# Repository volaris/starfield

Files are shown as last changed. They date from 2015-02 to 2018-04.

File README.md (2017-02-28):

Starfield
=========

Software (simulation and control) and electronics for the starfield display.

## Overview

The Starfield is a large grid of color controllable LEDs. They're spaced on vertical strands so that people can walk through them. People will be able to watch it from afar, walk through, or lounge in the space. There will be ambient animations designed to calm and intrigue. Calming music will play throughout the space. At certain times a DJ can connect to the Starfield or it picks up noise in the environment and displays animations that enhance and respond to that sound. IR cameras will detect where people are in the space and how active they are and modify the animations to respond to them. In the future, hand tracking stations will be used to create an individual or collaborative animation looper. Other methods of interaction such as converting EEG patterns to light are being investigated. The first version is a prototype designed to fit in a living room. A 20'x20'x20' version is being constructed for [Critical NW 2015](http://www.criticalnw.org/) and an even larger one is being planned for Burning Man 2016.

## Get Involved

Read the developer's guide and documentation at [volaris.github.io/starfield](http://volaris.github.io/starfield/)

## Technical Details

The core of the Starfield is driven by a [Fadecandy](https://github.com/scanlime/fadecandy) running on a [Raspberry Pi](https://www.raspberrypi.org/).

### Prototype

The prototype Starfield is a 7x5x4 voxel grid designed for hardware, animation, and construction technique testing.

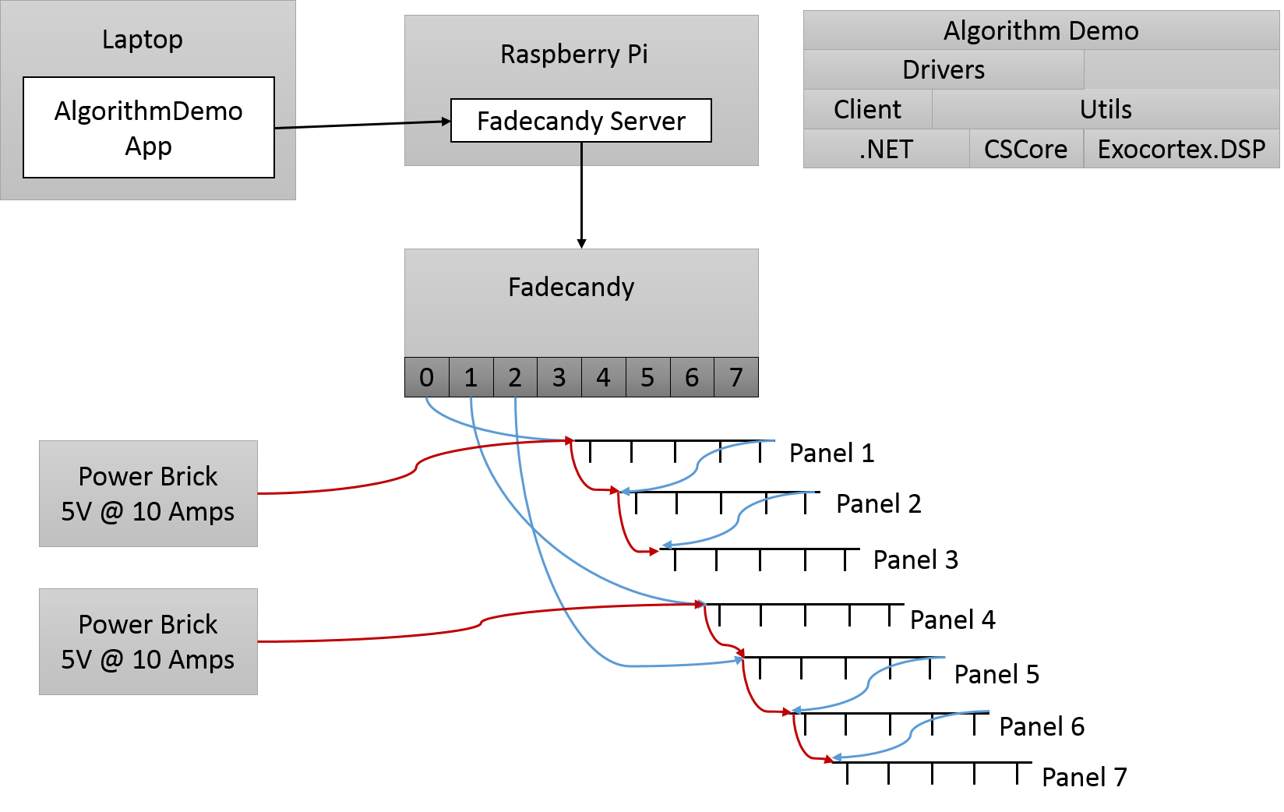
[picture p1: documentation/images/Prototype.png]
Prototype Diagram


### Critical NW

The Critical NW Starfield is a 11x11x10 voxel grid.

### Burning Man

The Burning Man Starfield is a 16x16x15 voxel grid.

## Repository Layout
```
/starfield
    /controllers - Starfield drivers and control software
        /AlgorithmDemo - Single display algorithm wrapper, displays list of all available drivers and their configuration options
        /Ambient - Randomly cycles through ambient algorithms
        /DualController - like AlgorithmDemo except it splits the display and displays two different algorithms
        /StarfieldDrivers - all of the driver classes, the controllers listed above use reflection to enumerate the drivers and their types from this library
    /docs - Starfield documentation for generating [volaris.github.io/starfield](http://volaris.github.io/starfield/)
    /documentation - Papers, datasheets, images related to algorithms 
    /electronics - Electronics designs: power distribution, voxel design, etc.
    /lib - Shared code and utility classes
        /.NET - .NET utility classes
            /StarfieldClient - base starfield classes, types, and interfaces (includes display model, driver interface, and network protocols)
            /Utils - Math, color, sound, and other algorithm utilities
        /external - 3rd party libraries
    /mechanical - Mechanical engineering designs and calculations for the structure
    /simulator - Unity simulator
```

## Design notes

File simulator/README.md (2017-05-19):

Starfield
=========

Unity based simulator for the starfield.

## Usage

After running the executable, use the configuration panel to generate the Starfield size that you want to interract with.
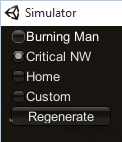
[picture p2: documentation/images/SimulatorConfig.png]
Simulator Config


## Connecting

The simulator opens a localhost TCP socket on port 7890 (127.0.0.1:7890). This socket accepts OPC pixel data.

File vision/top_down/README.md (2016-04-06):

Starfield Vision System
=======================

Software to capture and process IR images. This version assumes that cameras are facing straight down from the center support structure.

## image_aggregator.py
Retrieves the images from the remote cameras and prepares them for image_blender.py.

## image_blender.py
Takes the 5 images and blends them into a single image for heat map processing.

## image_processor.py
Takes the output from image_blender.py and creates a json file indicating the current presence levels for each grid coordinate.

## activity_processor.py
Takes the current output from image_blender.py and combines it with historical data to get a change in presence measure. Outputs a json file.

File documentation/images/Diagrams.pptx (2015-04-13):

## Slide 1

AlgorithmDemo App

Laptop

Raspberry Pi

Fadecandy Server

Algorithm Demo

Drivers

Utils

.NET

Client

CSCore

Exocortex.DSP

Fadecandy

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
Panel 1

Power Brick
5V @ 10 Amps

Power Brick
5V @ 10 Amps

Panel 2

Panel 3

Panel 4

Panel 5

Panel 6

Panel 7

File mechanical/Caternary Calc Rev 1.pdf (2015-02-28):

w 5

lbf
ft

:= Load per unit length

Half distance to support (a=x) | a | 50ft :=
Allowable Sag | S := 5ft
Guess for equation | c := 32ft

Given

S | c cosh a
| c

− 1

= ⋅

c
1

:= Find c( )

Caternary parameter | c
1

= 250.829 ft

s c
1

sinh a
c
1

:= ⋅

Length of cable to half (L=s) | s | 50.332 ft =

y
d

c
1
:= | + S
Height of post | y
d

= 255.829 ft

Tension at point of lowest sag | H | w c1
:= ⋅ | H | 1254.145 lbf =

Distributed Load
F := w s⋅ | F | 251.659 lbf =
Tension at support | T | w yd
:= ⋅ | T | 1279.145 lbf =

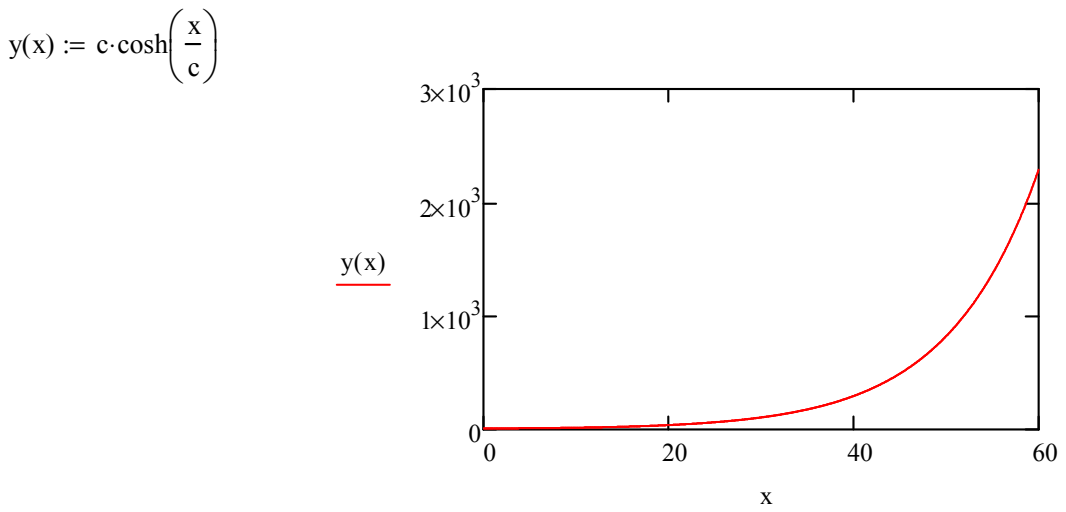
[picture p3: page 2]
c cosh

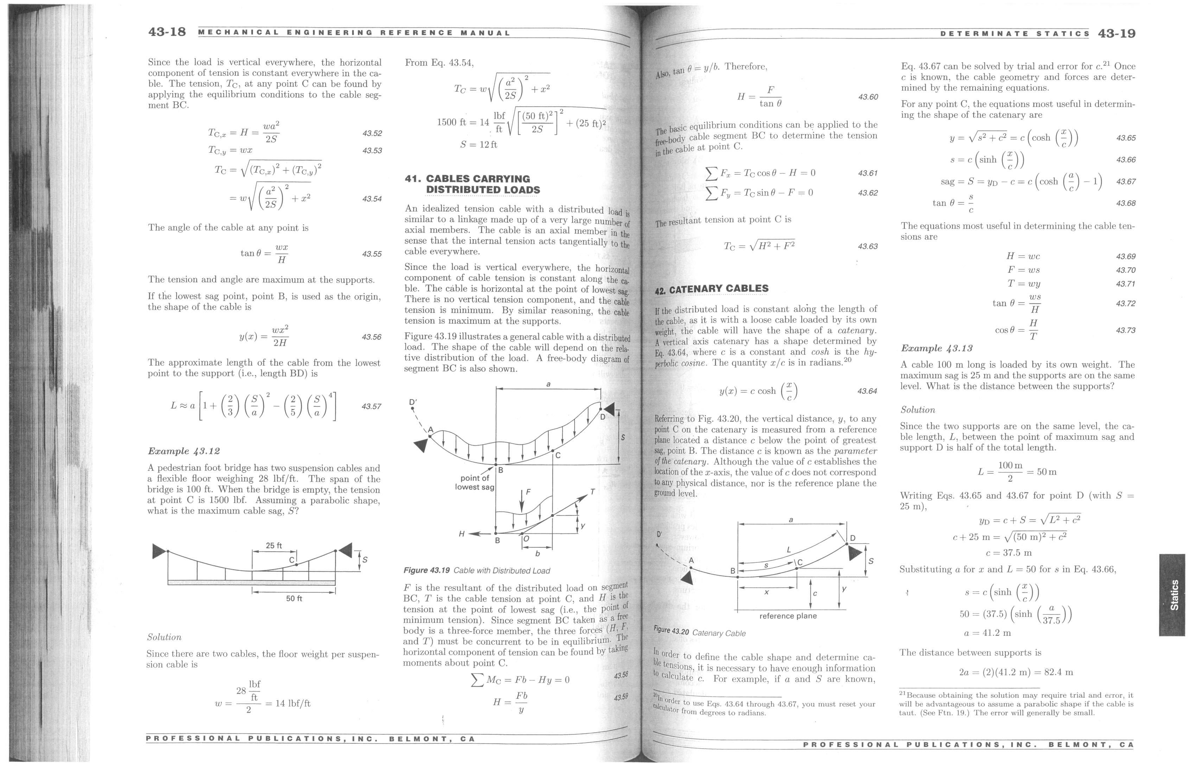
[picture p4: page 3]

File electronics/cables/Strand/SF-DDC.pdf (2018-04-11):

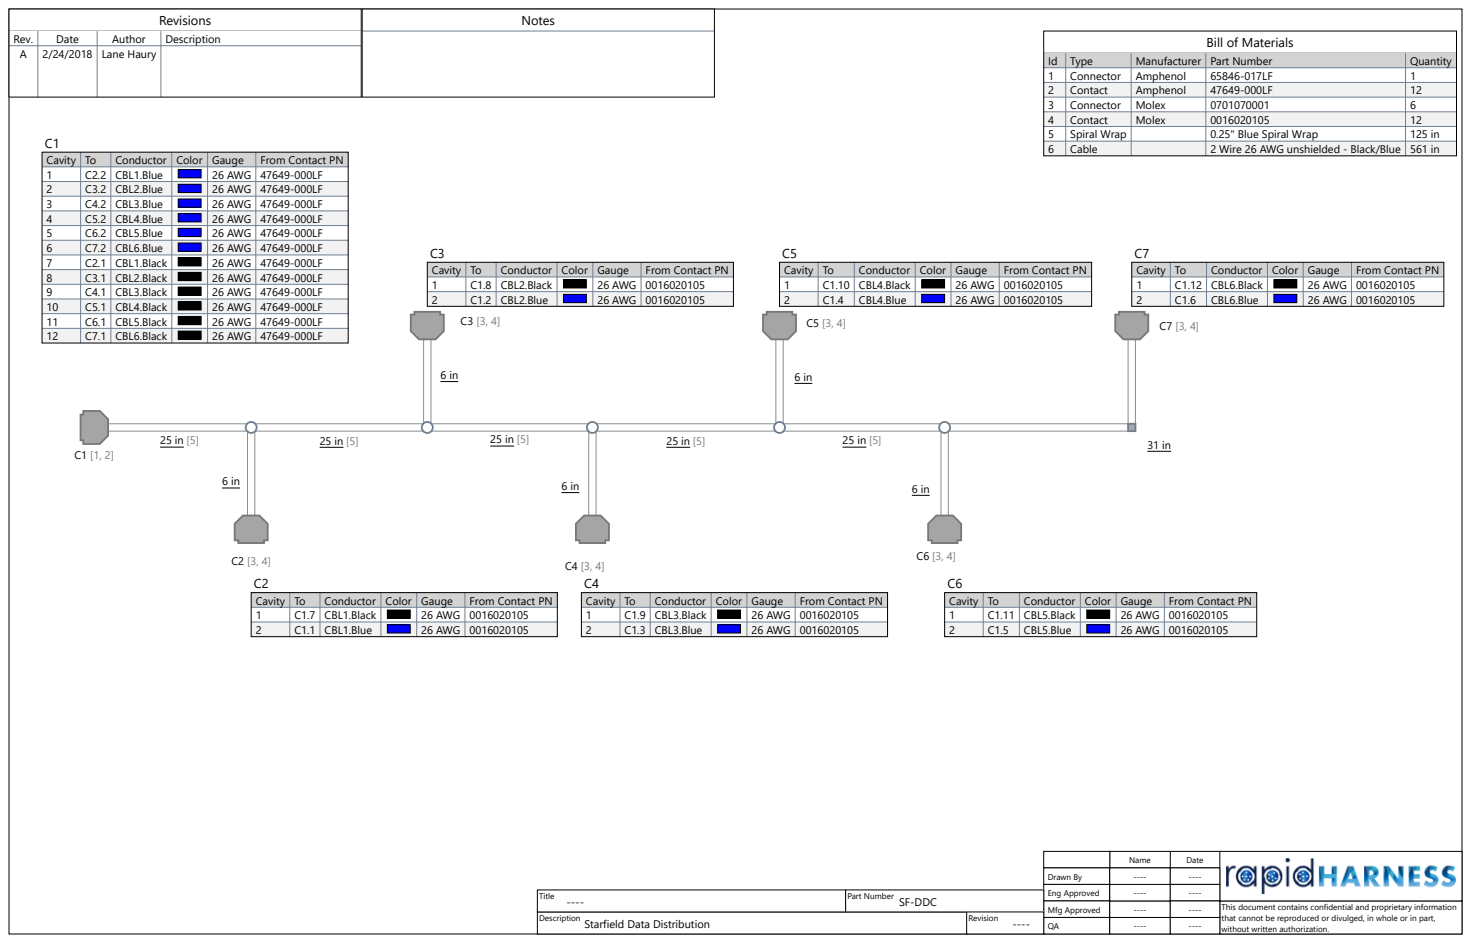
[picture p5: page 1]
Description; Name; Date; Drawn By; Eng Approved; Mfg Approved; Part Number; Revision; Title; SF-DDC; Starfield Data Distribution; Type; Manufacturer; Quantity; Connector; Amphenol; Contact; Molex; Spiral Wrap; 0.25" Blue Spiral Wrap; Cable; 2 Wire 26 AWG unshielded - Black/Blue; Revisions; Notes; Rev.; Author; Lane Haury; Cavity; Conductor; Color; Gauge; From Contact PN; CBL6.Black; 26 AWG; CBL6.Blue; CBL5.Black; CBL5.Blue; CBL4.Black; CBL4.Blue; CBL3.Black; CBL3.Blue; CBL2.Black; CBL2.Blue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

Bill of Materials

This document contains confidential and proprietary information
that cannot be reproduced or divulged, in whole or in part,
without written authorization.

Id | Type | Manufacturer | Part Number | Description | Quantity
1 | Connector | Amphenol | 65846-017LF | 2x6 Socket Connector | 1
2 | Contact | Amphenol | 47649-000LF | 22-26AWG Crimp Socket | 12
3 | Connector | Molex | 0701070001 | 2 pin locking | 6
4 | Contact | Molex | 0016020105 | 24-30AWG Pin | 12
5 | Spiral Wrap | | 0.25" Blue Spiral Wrap | Generic Spiral Wrap - Nylon | 125 in
6 | Cable | | 2 Wire 26 AWG unshielded - Black/Blue | Generic Cable | 561 in
Bill of Materials 1 of 1 | Page 2 of 5

Title:

Part Number: | SF-DDC
Description: | Starfield Data Distribution

From | To | Conductor | Conductor PN | Twist With | Gauge | Length | From Contact PN | Notes
C1.1 | C2.2 | CBL1.Blue | 2 Wire 26 AWG unshielded - Black/Blue | | 26 AWG | 31 in | 47649-000LF
C1.2 | C3.2 | CBL2.Blue | 2 Wire 26 AWG unshielded - Black/Blue | | 26 AWG | 56 in | 47649-000LF
C1.3 | C4.2 | CBL3.Blue | 2 Wire 26 AWG unshielded - Black/Blue | | 26 AWG | 81 in | 47649-000LF
C1.4 | C5.2 | CBL4.Blue | 2 Wire 26 AWG unshielded - Black/Blue | | 26 AWG | 106 in | 47649-000LF
C1.5 | C6.2 | CBL5.Blue | 2 Wire 26 AWG unshielded - Black/Blue | | 26 AWG | 131 in | 47649-000LF
C1.6 | C7.2 | CBL6.Blue | 2 Wire 26 AWG unshielded - Black/Blue | | 26 AWG | 156 in | 47649-000LF
C1.7 | C2.1 | CBL1.Black | 2 Wire 26 AWG unshielded - Black/Blue | | 26 AWG | 31 in | 47649-000LF
C1.8 | C3.1 | CBL2.Black | 2 Wire 26 AWG unshielded - Black/Blue | | 26 AWG | 56 in | 47649-000LF
C1.9 | C4.1 | CBL3.Black | 2 Wire 26 AWG unshielded - Black/Blue | | 26 AWG | 81 in | 47649-000LF
C1.10 | C5.1 | CBL4.Black | 2 Wire 26 AWG unshielded - Black/Blue | | 26 AWG | 106 in | 47649-000LF
C1.11 | C6.1 | CBL5.Black | 2 Wire 26 AWG unshielded - Black/Blue | | 26 AWG | 131 in | 47649-000LF
C1.12 | C7.1 | CBL6.Black | 2 Wire 26 AWG unshielded - Black/Blue | | 26 AWG | 156 in | 47649-000LF
Wiring Table 1 of 1 | Page 3 of 5

Description:

Starfield Data Distribution

# | Type | Reference Designator | Manufacturer | Part Number | Color | Gauge | Length | Twisted With

1 | Cable | CBL1 | 2 Wire 26 AWG unshielded - Black/Blue | White | 31 in
2 | Cable | CBL2 | 2 Wire 26 AWG unshielded - Black/Blue | White | 56 in
3 | Cable | CBL3 | 2 Wire 26 AWG unshielded - Black/Blue | White | 81 in
4 | Cable | CBL4 | 2 Wire 26 AWG unshielded - Black/Blue | White | 106 in
5 | Cable | CBL5 | 2 Wire 26 AWG unshielded - Black/Blue | White | 131 in
6 | Cable | CBL6 | 2 Wire 26 AWG unshielded - Black/Blue | White | 156 in
Cutlist 1 of 1 | Page 4 of 5

Description:

Starfield Data Distribution

# | Manufacturer | Part Number | Description | Label Text

Labels 1 of 1 | Page 5 of 5

Description:

Starfield Data Distribution

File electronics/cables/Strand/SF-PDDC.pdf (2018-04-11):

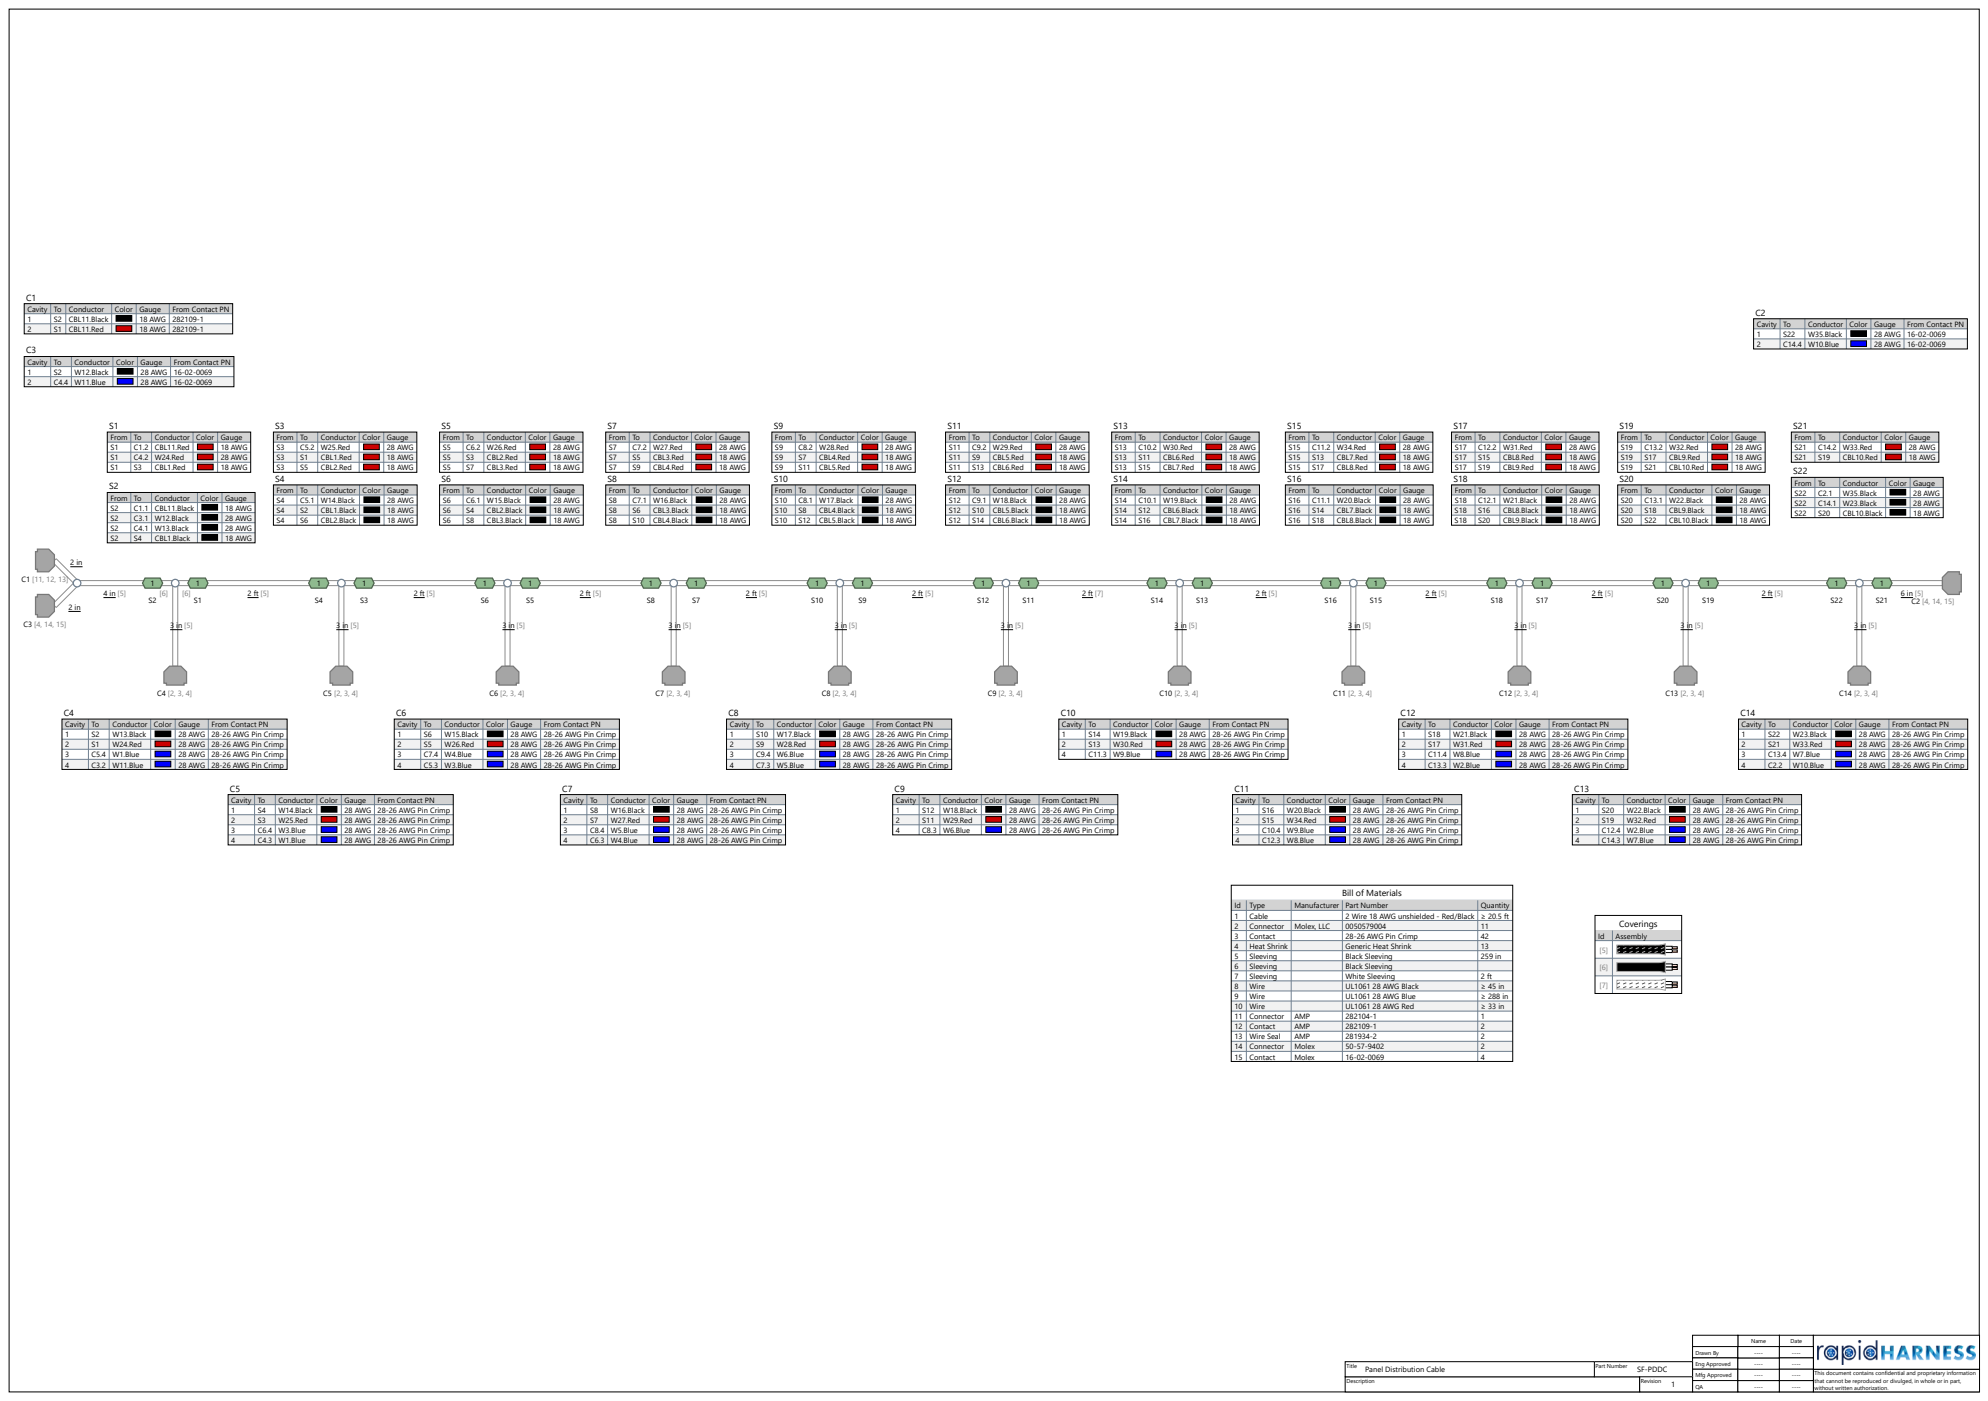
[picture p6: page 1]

This document contains confidential and proprietary information
that cannot be reproduced or divulged, in whole or in part,
without written authorization.

Id | Type | Manufacturer | Part Number | Description | Quantity
1 | Cable | | 2 Wire 18 AWG unshielded - Red/Black | Generic Cable | ≥ 20.5 ft
2 | Connector | Molex, LLC | 0050579004 | CONN HOUSING 4POS .100 SINGLE | 11
3 | Contact | | 28-26 AWG Pin Crimp | Generic Contact | 42
4 | Heat Shrink | | Generic Heat Shrink | Generic Heat Shrink | 13
5 | Sleeving | | Black Sleeving | Generic Sleeving - Kevlar, Braided | 259 in
6 | Sleeving | | Black Sleeving | Generic Sleeving - Kevlar
7 | Sleeving | | White Sleeving | Generic Sleeving - Kevlar, Braided | 2 ft
8 | Wire | | UL1061 28 AWG Black | UL 1061 rated 28 AWG Black SR-PVC Hook-up wire | ≥ 45 in
9 | Wire | | UL1061 28 AWG Blue | UL 1061 rated 28 AWG Blue SR-PVC Hook-up wire | ≥ 288 in
10 | Wire | | UL1061 28 AWG Red | UL 1061 rated 28 AWG Red SR-PVC Hook-up wire | ≥ 33 in
11 | Connector | AMP | 282104-1 | AMP SUPERSEAL 1.5 SERIES 2P CA | 1
12 | Contact | AMP | 282109-1 | AMP MINI MIC TAB CONTACT | 2
13 | Wire Seal | AMP | 281934-2 | Amp SuperSeal 1.5 Single Wire Seal | 2
14 | Connector | Molex | 50-57-9402 | 2 Position Rectangular Housing Connector Receptacle Black 0.100" (2.54mm) 2
15 | Contact | Molex | 16-02-0069 | Socket Contact Tin 24-30 AWG Crimp
Bill of Materials 1 of 1 | Page 2 of 6

# Part Number:

# Title:

# Description:

From | To | Conductor | Conductor PN | Twist With | Gauge | Length | From Contact PN | Notes
C1.1 | S2 | CBL11.Black | 2 Wire 18 AWG unshielded - Red/Black | | 18 AWG | ≥ 6 in | 282109-1
C1.2 | S1 | CBL11.Red | 2 Wire 18 AWG unshielded - Red/Black | | 18 AWG | ≥ 6 in | 282109-1
C2.1 | S22 | W35.Black | UL1061 28 AWG Black | | 28 AWG | ≥ 6 in | 16-02-0069
C2.2 | C14.4 | W10.Blue | UL1061 28 AWG Blue | | 28 AWG | ≥ 9 in | 16-02-0069
C3.1 | S2 | W12.Black | UL1061 28 AWG Black | | 28 AWG | 6 in | 16-02-0069
C3.2 | C4.4 | W11.Blue | UL1061 28 AWG Blue | | 28 AWG | ≥ 9 in | 16-02-0069
C4.1 | S2 | W13.Black | UL1061 28 AWG Black | | 28 AWG | ≥ 3 in | 28-26 AWG Pin Crimp
C4.2 | S1 | W24.Red | UL1061 28 AWG Red | | 28 AWG | ≥ 3 in | 28-26 AWG Pin Crimp
C4.3 | C5.4 | W1.Blue | UL1061 28 AWG Blue | | 28 AWG | ≥ 30 in | 28-26 AWG Pin Crimp
C5.1 | S4 | W14.Black | UL1061 28 AWG Black | | 28 AWG | ≥ 3 in | 28-26 AWG Pin Crimp
C5.2 | S3 | W25.Red | UL1061 28 AWG Red | | 28 AWG | ≥ 3 in | 28-26 AWG Pin Crimp
C5.3 | C6.4 | W3.Blue | UL1061 28 AWG Blue | | 28 AWG | ≥ 30 in | 28-26 AWG Pin Crimp
C6.1 | S6 | W15.Black | UL1061 28 AWG Black | | 28 AWG | ≥ 3 in | 28-26 AWG Pin Crimp
C6.2 | S5 | W26.Red | UL1061 28 AWG Red | | 28 AWG | ≥ 3 in | 28-26 AWG Pin Crimp
C6.3 | C7.4 | W4.Blue | UL1061 28 AWG Blue | | 28 AWG | ≥ 30 in | 28-26 AWG Pin Crimp
C7.1 | S8 | W16.Black | UL1061 28 AWG Black | | 28 AWG | ≥ 3 in | 28-26 AWG Pin Crimp
C7.2 | S7 | W27.Red | UL1061 28 AWG Red | | 28 AWG | ≥ 3 in | 28-26 AWG Pin Crimp
C7.3 | C8.4 | W5.Blue | UL1061 28 AWG Blue | | 28 AWG | ≥ 30 in | 28-26 AWG Pin Crimp
C8.1 | S10 | W17.Black | UL1061 28 AWG Black | | 28 AWG | ≥ 3 in | 28-26 AWG Pin Crimp
C8.2 | S9 | W28.Red | UL1061 28 AWG Red | | 28 AWG | ≥ 3 in | 28-26 AWG Pin Crimp
C8.3 | C9.4 | W6.Blue | UL1061 28 AWG Blue | | 28 AWG | ≥ 30 in | 28-26 AWG Pin Crimp
C9.1 | S12 | W18.Black | UL1061 28 AWG Black | | 28 AWG | ≥ 3 in | 28-26 AWG Pin Crimp
C9.2 | S11 | W29.Red | UL1061 28 AWG Red | | 28 AWG | ≥ 3 in | 28-26 AWG Pin Crimp
C10.1 | S14 | W19.Black | UL1061 28 AWG Black | | 28 AWG | ≥ 3 in | 28-26 AWG Pin Crimp
C10.2 | S13 | W30.Red | UL1061 28 AWG Red | | 28 AWG | ≥ 3 in | 28-26 AWG Pin Crimp
C11.1 | S16 | W20.Black | UL1061 28 AWG Black | | 28 AWG | ≥ 3 in | 28-26 AWG Pin Crimp
C11.2 | S15 | W34.Red | UL1061 28 AWG Red | | 28 AWG | ≥ 3 in | 28-26 AWG Pin Crimp
C11.3 | C10.4 | W9.Blue | UL1061 28 AWG Blue | | 28 AWG | ≥ 30 in | 28-26 AWG Pin Crimp
C12.1 | S18 | W21.Black | UL1061 28 AWG Black | | 28 AWG | ≥ 3 in | 28-26 AWG Pin Crimp
C12.2 | S17 | W31.Red | UL1061 28 AWG Red | | 28 AWG | ≥ 3 in | 28-26 AWG Pin Crimp
C12.3 | C11.4 | W8.Blue | UL1061 28 AWG Blue | | 28 AWG | ≥ 30 in | 28-26 AWG Pin Crimp
C13.1 | S20 | W22.Black | UL1061 28 AWG Black | | 28 AWG | ≥ 3 in | 28-26 AWG Pin Crimp
C13.2 | S19 | W32.Red | UL1061 28 AWG Red | | 28 AWG | ≥ 3 in | 28-26 AWG Pin Crimp
C13.3 | C12.4 | W2.Blue | UL1061 28 AWG Blue | | 28 AWG | ≥ 30 in | 28-26 AWG Pin Crimp
C14.1 | S22 | W23.Black | UL1061 28 AWG Black | | 28 AWG | ≥ 3 in | 28-26 AWG Pin Crimp
C14.2 | S21 | W33.Red | UL1061 28 AWG Red | | 28 AWG | ≥ 3 in | 28-26 AWG Pin Crimp
C14.3 | C13.4 | W7.Blue | UL1061 28 AWG Blue | | 28 AWG | ≥ 30 in | 28-26 AWG Pin Crimp
S1 | S3 | CBL1.Red | 2 Wire 18 AWG unshielded - Red/Black | | 18 AWG | ≥ 2 ft
S2 | S4 | CBL1.Black | 2 Wire 18 AWG unshielded - Red/Black | | 18 AWG | ≥ 2 ft
S3 | S5 | CBL2.Red | 2 Wire 18 AWG unshielded - Red/Black | | 18 AWG | ≥ 2 ft
S4 | S6 | CBL2.Black | 2 Wire 18 AWG unshielded - Red/Black | | 18 AWG | ≥ 2 ft
S5 | S7 | CBL3.Red | 2 Wire 18 AWG unshielded - Red/Black | | 18 AWG | ≥ 2 ft
S6 | S8 | CBL3.Black | 2 Wire 18 AWG unshielded - Red/Black | | 18 AWG | ≥ 2 ft
S7 | S9 | CBL4.Red | 2 Wire 18 AWG unshielded - Red/Black | | 18 AWG | ≥ 2 ft
S8 | S10 | CBL4.Black | 2 Wire 18 AWG unshielded - Red/Black | | 18 AWG | ≥ 2 ft
S9 | S11 | CBL5.Red | 2 Wire 18 AWG unshielded - Red/Black | | 18 AWG | ≥ 2 ft
S10 | S12 | CBL5.Black | 2 Wire 18 AWG unshielded - Red/Black | | 18 AWG | ≥ 2 ft
S11 | S13 | CBL6.Red | 2 Wire 18 AWG unshielded - Red/Black | | 18 AWG | ≥ 2 ft
S13 | S15 | CBL7.Red | 2 Wire 18 AWG unshielded - Red/Black | | 18 AWG | ≥ 2 ft
S14 | S12 | CBL6.Black | 2 Wire 18 AWG unshielded - Red/Black | | 18 AWG | ≥ 2 ft
S14 | S16 | CBL7.Black | 2 Wire 18 AWG unshielded - Red/Black | | 18 AWG | ≥ 2 ft
S15 | S17 | CBL8.Red | 2 Wire 18 AWG unshielded - Red/Black | | 18 AWG | ≥ 2 ft
S16 | S18 | CBL8.Black | 2 Wire 18 AWG unshielded - Red/Black | | 18 AWG | ≥ 2 ft
S17 | S19 | CBL9.Red | 2 Wire 18 AWG unshielded - Red/Black | | 18 AWG | ≥ 2 ft
S18 | S20 | CBL9.Black | 2 Wire 18 AWG unshielded - Red/Black | | 18 AWG | ≥ 2 ft
S19 | S21 | CBL10.Red | 2 Wire 18 AWG unshielded - Red/Black | | 18 AWG | ≥ 2 ft
Wiring Table 1 of 2 | Page 3 of 6

From | To | Conductor | Conductor PN | Twist With | Gauge | Length | From Contact PN | Notes
S20 | S22 | CBL10.Black | 2 Wire 18 AWG unshielded - Red/Black | | 18 AWG | ≥ 2 ft
Wiring Table 2 of 2 | Page 4 of 6

# | Type | Reference Designator | Manufacturer | Part Number | Color | Gauge | Length | Twisted With

1 | Cable | CBL1 | 2 Wire 18 AWG unshielded - Red/Black | White | ≥ 2 ft
2 | Cable | CBL2 | 2 Wire 18 AWG unshielded - Red/Black | White | ≥ 2 ft
3 | Cable | CBL3 | 2 Wire 18 AWG unshielded - Red/Black | White | ≥ 2 ft
4 | Cable | CBL4 | 2 Wire 18 AWG unshielded - Red/Black | White | ≥ 2 ft
5 | Cable | CBL5 | 2 Wire 18 AWG unshielded - Red/Black | White | ≥ 2 ft
6 | Cable | CBL6 | 2 Wire 18 AWG unshielded - Red/Black | White | ≥ 2 ft
7 | Cable | CBL7 | 2 Wire 18 AWG unshielded - Red/Black | White | ≥ 2 ft
8 | Cable | CBL8 | 2 Wire 18 AWG unshielded - Red/Black | White | ≥ 2 ft
9 | Cable | CBL9 | 2 Wire 18 AWG unshielded - Red/Black | White | ≥ 2 ft
10 | Cable | CBL10 | 2 Wire 18 AWG unshielded - Red/Black | White | ≥ 2 ft
11 | Cable | CBL11 | 2 Wire 18 AWG unshielded - Red/Black | White | ≥ 6 in
12 | Wire | W1 | UL1061 28 AWG Blue | Blue | 28 AWG | ≥ 30 in
13 | Wire | W2 | UL1061 28 AWG Blue | Blue | 28 AWG | ≥ 30 in
14 | Wire | W3 | UL1061 28 AWG Blue | Blue | 28 AWG | ≥ 30 in
15 | Wire | W4 | UL1061 28 AWG Blue | Blue | 28 AWG | ≥ 30 in
16 | Wire | W5 | UL1061 28 AWG Blue | Blue | 28 AWG | ≥ 30 in
17 | Wire | W6 | UL1061 28 AWG Blue | Blue | 28 AWG | ≥ 30 in
18 | Wire | W7 | UL1061 28 AWG Blue | Blue | 28 AWG | ≥ 30 in
19 | Wire | W8 | UL1061 28 AWG Blue | Blue | 28 AWG | ≥ 30 in
20 | Wire | W9 | UL1061 28 AWG Blue | Blue | 28 AWG | ≥ 30 in
21 | Wire | W10 | UL1061 28 AWG Blue | Blue | 28 AWG | ≥ 9 in
22 | Wire | W11 | UL1061 28 AWG Blue | Blue | 28 AWG | ≥ 9 in
23 | Wire | W12 | UL1061 28 AWG Black | Black | 28 AWG | 6 in
24 | Wire | W13 | UL1061 28 AWG Black | Black | 28 AWG | ≥ 3 in
25 | Wire | W14 | UL1061 28 AWG Black | Black | 28 AWG | ≥ 3 in
26 | Wire | W15 | UL1061 28 AWG Black | Black | 28 AWG | ≥ 3 in
27 | Wire | W16 | UL1061 28 AWG Black | Black | 28 AWG | ≥ 3 in
28 | Wire | W17 | UL1061 28 AWG Black | Black | 28 AWG | ≥ 3 in
29 | Wire | W18 | UL1061 28 AWG Black | Black | 28 AWG | ≥ 3 in
30 | Wire | W19 | UL1061 28 AWG Black | Black | 28 AWG | ≥ 3 in
31 | Wire | W20 | UL1061 28 AWG Black | Black | 28 AWG | ≥ 3 in
32 | Wire | W21 | UL1061 28 AWG Black | Black | 28 AWG | ≥ 3 in
33 | Wire | W22 | UL1061 28 AWG Black | Black | 28 AWG | ≥ 3 in
34 | Wire | W23 | UL1061 28 AWG Black | Black | 28 AWG | ≥ 3 in
35 | Wire | W24 | UL1061 28 AWG Red | Red | 28 AWG | ≥ 3 in
36 | Wire | W25 | UL1061 28 AWG Red | Red | 28 AWG | ≥ 3 in
37 | Wire | W26 | UL1061 28 AWG Red | Red | 28 AWG | ≥ 3 in
38 | Wire | W27 | UL1061 28 AWG Red | Red | 28 AWG | ≥ 3 in
39 | Wire | W28 | UL1061 28 AWG Red | Red | 28 AWG | ≥ 3 in
40 | Wire | W29 | UL1061 28 AWG Red | Red | 28 AWG | ≥ 3 in
41 | Wire | W30 | UL1061 28 AWG Red | Red | 28 AWG | ≥ 3 in
42 | Wire | W31 | UL1061 28 AWG Red | Red | 28 AWG | ≥ 3 in
43 | Wire | W32 | UL1061 28 AWG Red | Red | 28 AWG | ≥ 3 in
44 | Wire | W33 | UL1061 28 AWG Red | Red | 28 AWG | ≥ 3 in
45 | Wire | W34 | UL1061 28 AWG Red | Red | 28 AWG | ≥ 3 in
46 | Wire | W35 | UL1061 28 AWG Black | Black | 28 AWG | ≥ 6 in
Cutlist 1 of 1 | Page 5 of 6

# | Manufacturer | Part Number | Description | Label Text

Labels 1 of 1 | Page 6 of 6

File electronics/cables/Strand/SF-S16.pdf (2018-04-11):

QA

C2

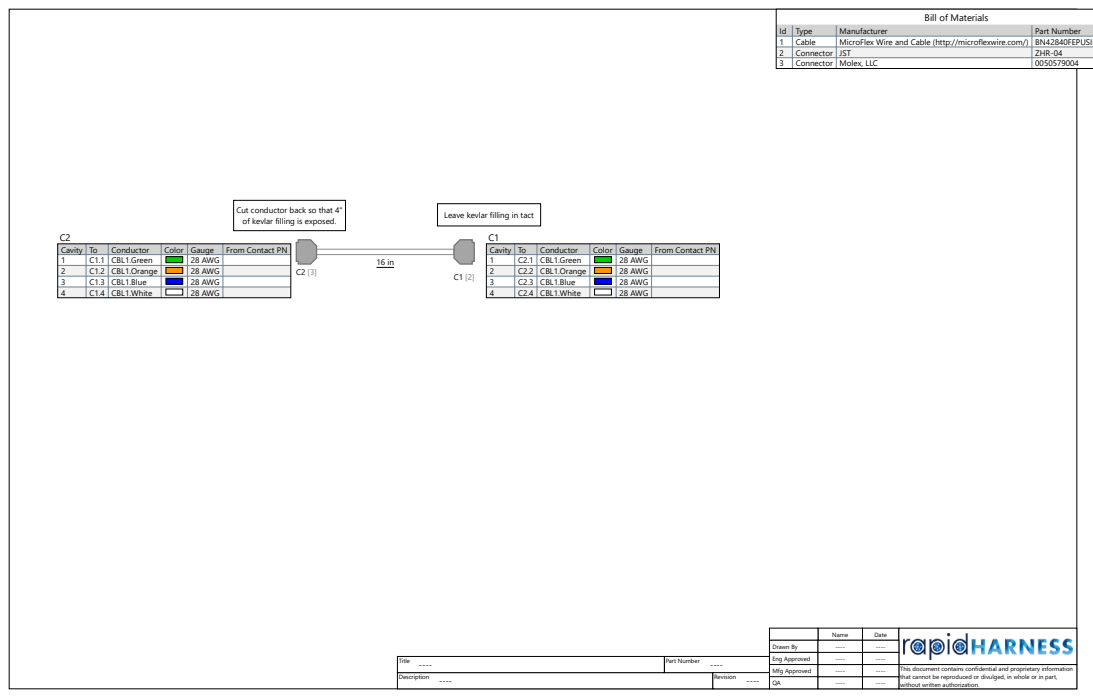
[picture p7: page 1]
Description; Mfg Approved; Part Number; Revision; Title

Bill of Materials

Id Type Manufacturer Part Number Quantity
1 Cable MicroFlex Wire and Cable (http://microflexwire.com/) BN42840FEPUSIL 16 in
2 Connector JST ZHR-04 1
3 Connector Molex, LLC 0050579004 1
of kevlar filling is exposed. Leave kevlar filling in tact
Cavity To Conductor Color Gauge From Contact PN
1 C1.1 CBL1.Green 28 AWG
2 C1.2 CBL1.Orange 28 AWG
3 C1.3 CBL1.Blue 28 AWG
4 C1.4 CBL1.White 28 AWG

Cut conductor back so that 4"
1 C2.1 CBL1.Green 28 AWG
2 C2.2 CBL1.Orange 28 AWG
3 C2.3 CBL1.Blue 28 AWG
4 C2.4 CBL1.White 28 AWG

Name Date
Drawn By
Eng Approved
This document contains confidential and proprietary information
that cannot be reproduced or divulged, in whole or in part,
without written authorization.

## Id Type Manufacturer Part Number Description Quantity

1 Cable MicroFlex Wire and Cable (http://microflexwire.com/) BN42840FEPUSIL 4 Conductor Twisted with Kevlar Colors 16 in

## 2 Connector JST ZHR-04 4 circuit ZH connector housing, white 1

## 3 Connector Molex, LLC 0050579004 CONN HOUSING 4POS .100 SINGLE 1

## Bill of Materials 1 of 1 Page 2 of 5

Title:

Part Number:

Description:

## From To Conductor Conductor PN Twist With Gauge Length From Contact PN Notes

C1.1 C2.1 CBL1.Green BN42840FEPUSIL 28 AWG 16 in
C1.2 C2.2 CBL1.Orange BN42840FEPUSIL 28 AWG 16 in
C1.3 C2.3 CBL1.Blue BN42840FEPUSIL 28 AWG 16 in
C1.4 C2.4 CBL1.White BN42840FEPUSIL 28 AWG 16 in

## Wiring Table 1 of 1 Page 3 of 5

Description:

## # Type Reference Designator Manufacturer Part Number Color Gauge Length Twisted With

1 Cable CBL1 MicroFlex Wire and Cable (http://microflexwire.com/) BN42840FEPUSIL Black 16 in

## Cutlist 1 of 1 Page 4 of 5

Description:

### # Manufacturer Part Number Description Label Text

## Labels 1 of 1 Page 5 of 5

Description:

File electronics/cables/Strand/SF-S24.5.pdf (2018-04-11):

QA

A

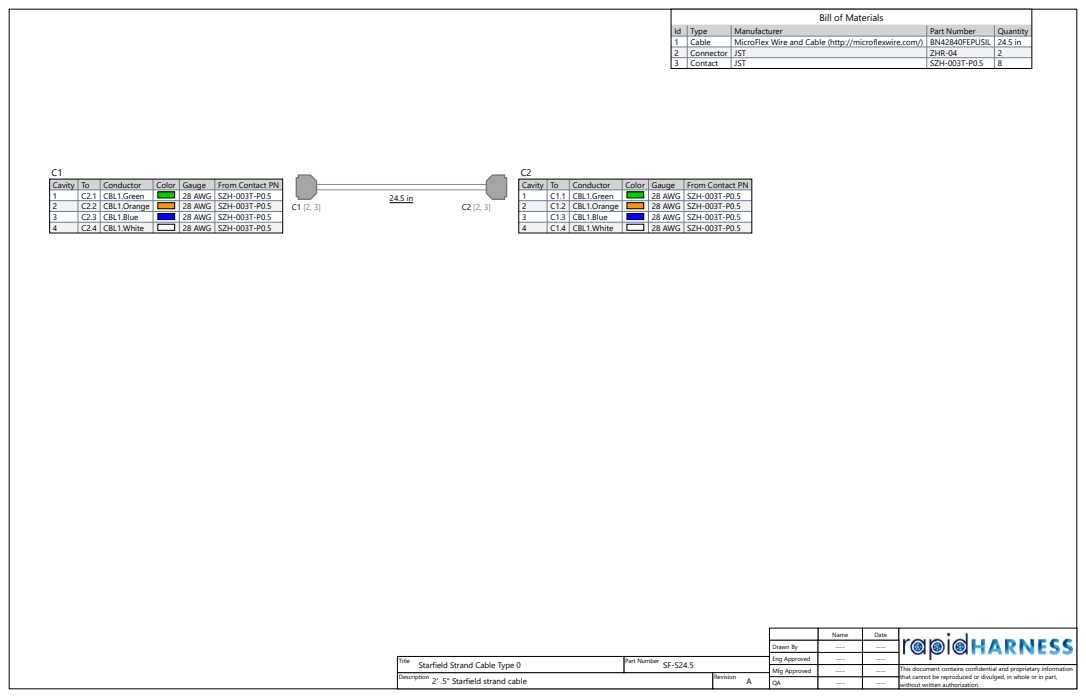
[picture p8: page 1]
Description; Mfg Approved; Part Number; Revision

Bill of Materials

Id Type Manufacturer Part Number Quantity
1 Cable MicroFlex Wire and Cable (http://microflexwire.com/) BN42840FEPUSIL 24.5 in
2 Connector JST ZHR-04 2
3 Contact JST SZH-003T-P0.5 8
Cavity To Conductor Color Gauge From Contact PN
1 C1.1 CBL1.Green 28 AWG SZH-003T-P0.5
2 C1.2 CBL1.Orange 28 AWG SZH-003T-P0.5
3 C1.3 CBL1.Blue 28 AWG SZH-003T-P0.5
4 C1.4 CBL1.White 28 AWG SZH-003T-P0.5
Title SF-S24.5
2' .5" Starfield strand cable ----

1 C2.1 CBL1.Green 28 AWG SZH-003T-P0.5
2 C2.2 CBL1.Orange 28 AWG SZH-003T-P0.5
3 C2.3 CBL1.Blue 28 AWG SZH-003T-P0.5
4 C2.4 CBL1.White 28 AWG SZH-003T-P0.5

Starfield Strand Cable Type 0

Name Date
Drawn By
Eng Approved
This document contains confidential and proprietary information
that cannot be reproduced or divulged, in whole or in part,
without written authorization.

Id Type Manufacturer Part Number Description Quantity 1 Cable MicroFlex Wire and Cable (http://microflexwire.com/) BN42840FEPUSIL 4 Conductor Twisted with Kevlar Colors 24.5 in

### 2 Connector JST ZHR-04 4 circuit ZH connector housing, white 2

### 3 Contact JST SZH-003T-P0.5 32-28 awg zh crimp pin 8

### Bill of Materials 1 of 1 Page 2 of 5

Title:

Part Number:

Description:

SF-S24.5
2' .5" Starfield strand cable

From To Conductor Conductor PN Twist With Gauge Length From Contact PN Notes C1.1 C2.1 CBL1.Green BN42840FEPUSIL 28 AWG 24.5 in SZH-003T-P0.5
C1.2 C2.2 CBL1.Orange BN42840FEPUSIL 28 AWG 24.5 in SZH-003T-P0.5
C1.3 C2.3 CBL1.Blue BN42840FEPUSIL 28 AWG 24.5 in SZH-003T-P0.5
C1.4 C2.4 CBL1.White BN42840FEPUSIL 28 AWG 24.5 in SZH-003T-P0.5

### Wiring Table 1 of 1 Page 3 of 5

Description:

2' .5" Starfield strand cable

# Type Reference Designator Manufacturer Part Number Color Gauge Length Twisted With 1 Cable CBL1 MicroFlex Wire and Cable (http://microflexwire.com/) BN42840FEPUSIL Black 24.5 in

### Cutlist 1 of 1 Page 4 of 5

Description:

2' .5" Starfield strand cable

# Manufacturer Part Number Description Label Text

### Labels 1 of 1 Page 5 of 5

Description:

2' .5" Starfield strand cable

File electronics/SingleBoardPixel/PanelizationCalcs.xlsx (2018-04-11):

0.06 |  |  | qty | fab cost | assembly | shipping | total | parts | grand total
0.75
0.5
5 | 4.25
7 | 3.86 | 26 | 30 | 60 | 456 | 42 | 558 | 265 | 823
 | 35
0.06
0.75
0.5
5 | 4.25
10 | 5.54 | 19 | 20 | 61 | 451 | 42 | 554 | 265 | 819
 | 50

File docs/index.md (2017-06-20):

---
layout: home
title: The Starfield
---
# The Starfield

## Getting Started

The topics in this section will help you install all of the required tools, become familiar with the test environment, and create your first Starfield plugin.

### Clone the Repo

[Clone or download the master branch](https://github.com/volaris/starfield)

### Requirements

* [Visual Studio](https://www.visualstudio.com/downloads/) Community or Pro editions

### Building Solutions

* Open solution starfield\lib\.NET\StarfieldLibs.sln
* Switch project configuration to Release mode
* Build solution
* You should see this: `========== Build: 2 succeeded, 0 failed, 0 up-to-date, 0 skipped ==========`
* Open solution starfield\controllers\StarfieldDrivers\StarfieldDrivers.sln
* Switch project configuration to Release mode
* Build solution
* You should see this: `========== Build: 1 succeeded, 0 failed, 0 up-to-date, 0 skipped ==========`

### Get the Simulator

Download the simulator
* [Linux](https://github.com/volaris/starfield/raw/master/simulator/builds/Linux.zip)
* [Mac](https://github.com/volaris/starfield/raw/master/simulator/builds/Mac.zip)
* [Windows](https://github.com/volaris/starfield/raw/master/simulator/builds/Windows.zip)

After running the executable, press *Play!* and use the configuration panel to generate the Starfield size that you want to interract with.

Simulator Config

You can move the camera around in the Simulator with WASD keys.

### Running the Demo

While the Simulator is running, start the demo.

1. Open solution starfield\controllers\AlgorithmDemo\AlgorithmDemo.sln
1. Switch project configuration to Release mode
1. Build solution
1. Run solution
1. Choose a Starfield (Critical NW Starfield)
1. Choose an algorithm (Smooth Rainbow Simplex Noise)

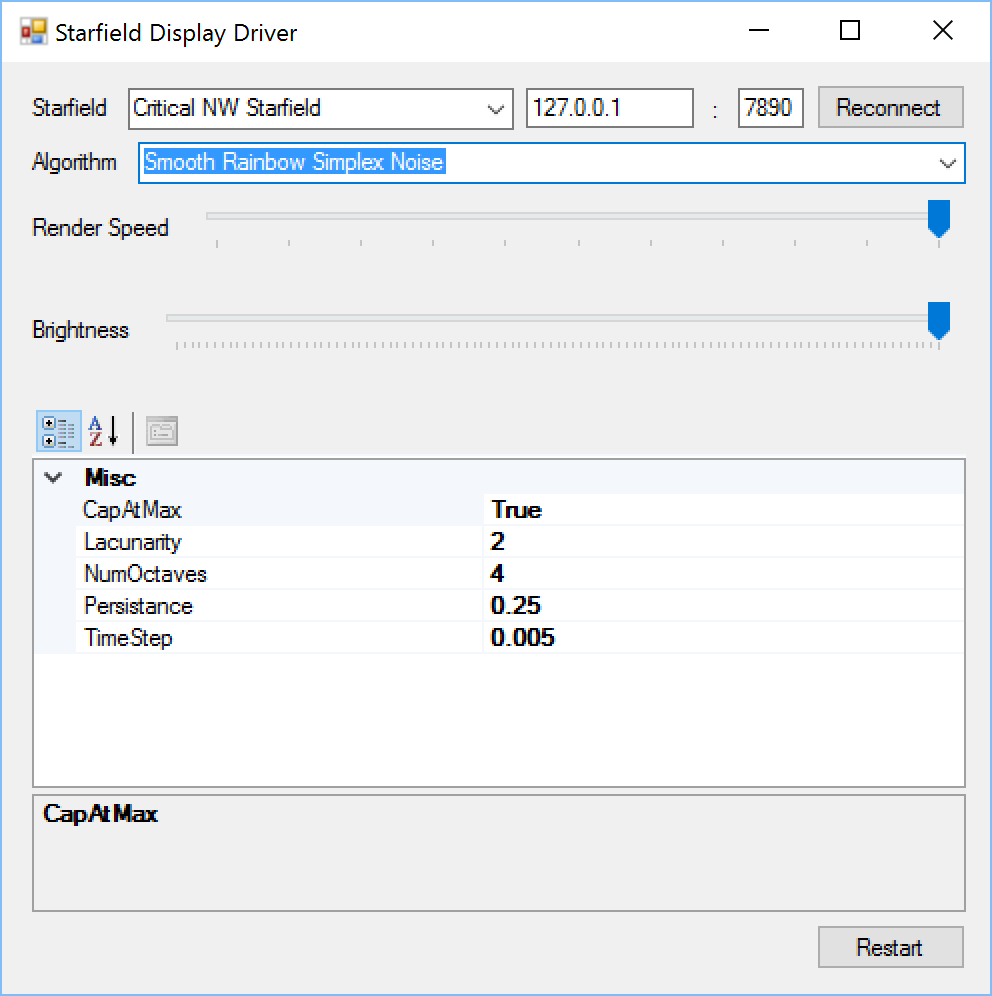
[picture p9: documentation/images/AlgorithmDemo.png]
Demo Config


### Testing the Client and Server

TBD

### Anatomy of an Algorithm

Starfield algorithms are included in the solution starfield\controllers\StarfieldDrivers\StarfieldDrivers.sln

Let's start with a simple example: TestFill.

```C#
    [DriverType(DriverTypes.Experimental)]
    public class TestFill : IStarfieldDriver
    {
    	...
    }
```

TestFill implements the IStarfieldDriver interface. 

```C#
    public interface IStarfieldDriver
    {
        void Render(StarfieldModel Starfield);

        void Start(StarfieldModel Starfield);

        void Stop();
    }
```

You can read the [IStarfieldDriver documentation](api/html/T_Starfield_IStarfieldDriver.htm). Then take a look at the source of [starfield\controllers\StarfieldDrivers\StarfieldDrivers\Test\TestFill.cs](https://github.com/volaris/starfield/blob/master/controllers/StarfieldDrivers/StarfieldDrivers/Test/TestFill.cs)

### How to Write a Starfield Plugin

Contributing directly to the Starfield project.

1. Open solution starfield\controllers\StarfieldDrivers\StarfieldDrivers.sln
1. Add your new class to one of the categories or create your own category (namespace)
	- Animation
	- CFD
	- Flocking
	- Fractal
	- Noise
	- PresenceResponsive
	- Projection
	- Sound Responsive
	- Test
1. Implement [IStarfieldDriver](api/html/T_Starfield_IStarfieldDriver.htm)
1. Build the project

Create your own Starfield algorithm project. This will allow you to compile a binary library (dll) and include it with an existing Starfield implemenation.

1. Start a new solution
1. Make sure you can [build the solution](#building-solutions)
1. Add a reference to starfield/controllers/bin/Starfield.dll
1. Optionally add a reference to starfield/controllers/bin/Utils.dll if you need extended math features

### Running the Simulator Over the Network

TBD

### Documentation

* [Namespaces](api/html/R_Project_Documentation.htm)

### Contributing

If you would like to contribute to this guide or the [API documentation](api/html/R_Project_Documentation.htm) follow these steps...

#### This guide
1. [Pull or fork the master branch](https://github.com/volaris/starfield/)
2. [Set up Jekyll](https://jekyllrb.com/docs/quickstart/). You'll need Ruby. Don't forget to `bundle`.
3. Run the local server `jekyll serve` from `starfield/docs`
4. Browse your local server `https://localhost:4000/starfield/` :warning: The trailing slash is important
5. Make edits
6. Commit changes
7. Make a pull request

#### API Docs
1. [Pull or fork the master branch](https://github.com/volaris/starfield/)
2. Make sure you can [build the solution](#building-solutions)
3. TBD

Need help with Markdown? [Basic writing and formatting syntax](https://help.github.com/articles/basic-writing-and-formatting-syntax/)

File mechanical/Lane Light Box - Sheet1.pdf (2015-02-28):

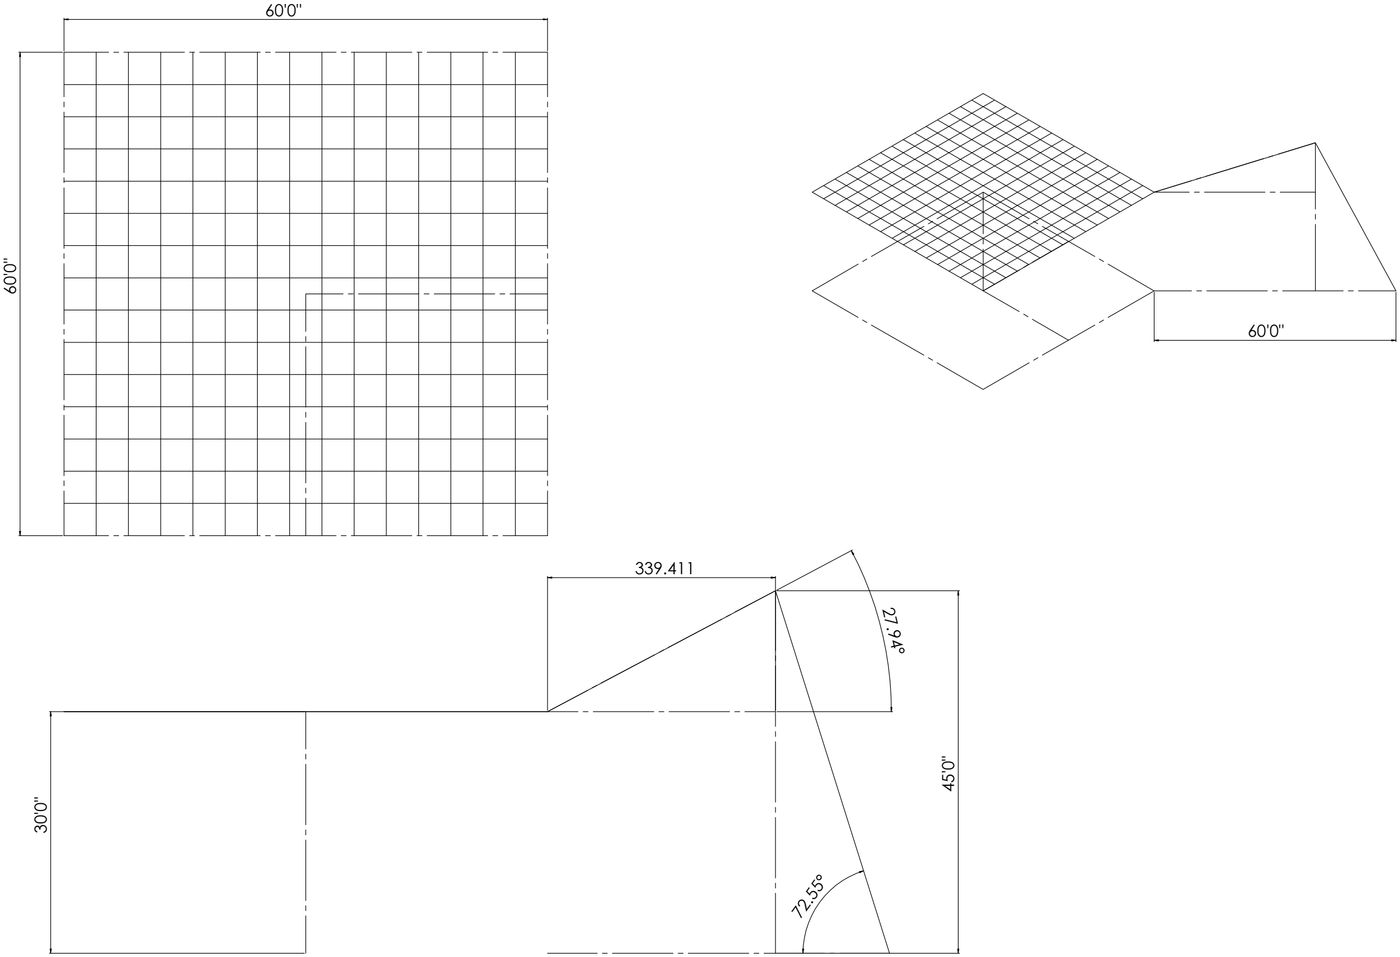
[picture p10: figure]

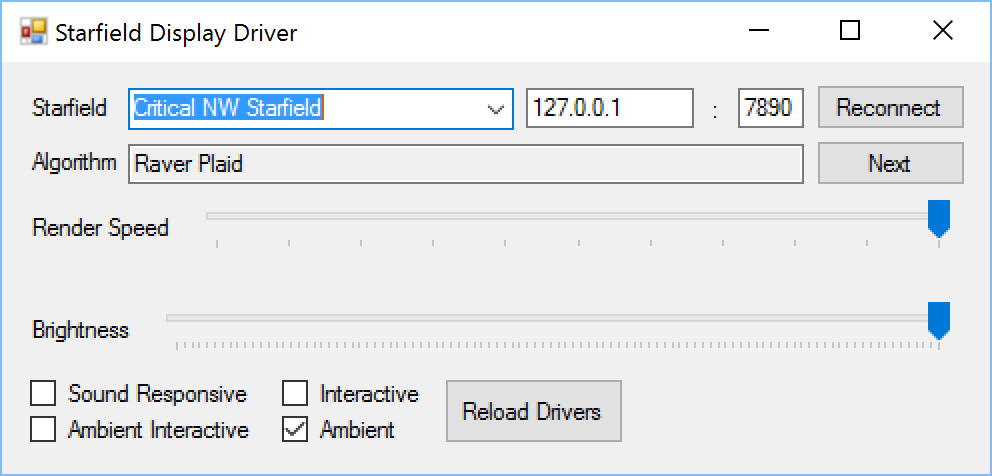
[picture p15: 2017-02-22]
documentation/images/Ambient.png

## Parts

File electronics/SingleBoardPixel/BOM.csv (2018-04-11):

Qty | Value | Device | Package | Parts | Description | MF | MPN
2 | .1uF | C-USC0402 | C0402 | C1, C2 | .1uF Capacitor | Taiyo Yuden | LMK105BJ104KV-F
2 | S4B-ZR | S4B-ZR | S4B-ZR | J1, J2 | ZH CONNECTOR 1.5 mm, 4 pin 1 row | JST | S4B-ZR(LF)(SN)
2 | WS2812B | WS2812B | SMD5050 | D1, D2 | WS2812B SMD addressable RGB LED | Worldsemi | WS2812B

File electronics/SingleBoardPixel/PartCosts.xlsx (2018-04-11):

Qty | Value | Device | Package | Parts | Description | MF | MPN | OC_FARNELL | OC_NEWARK | PROD_ID | VALUE | price
2 | .1uF | C-USC0402 | C0402 | C1, C2 | .1uF Capacitor | Taiyo Yuden | LMK105BJ104KV-F |  |  |  |  | 0.00335 | 0.0067
2 | S4B-ZR | S4B-ZR | S4B-ZR | J1, J2 | ZH CONNECTOR 1.5 mm, 4 pin 1 row | JST | S4B-ZR(LF)(SN) | 9491830 | 38K8076 |  |  | 0.10922 | 0.21844
2 | WS2812B | WS2812B | SMD5050 | D1, D2 | WS2812B SMD addressable RGB LED | Worldsemi | WS2812B |  |  | DIO-12503 | WS2812B | 0.02 | 0.04
 |  |  |  |  |  |  |  |  |  |  |  |  | 265.14 | 1000 | 605
 |  |  |  |  |  |  |  |  |  |  |  |  |  | 0.26514

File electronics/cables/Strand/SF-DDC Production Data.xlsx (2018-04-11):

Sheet: Bill of Materials
Bill of Materials
Type |  | Harness
Part Number |  | SF-DDC
Description |  | Starfield Data Distribution
Id | Type | Manufacturer | Part Number | Description | Quantity
1 | Connector | Amphenol | 65846-017LF | 2x6 Socket Connector | 1
2 | Contact | Amphenol | 47649-000LF | 22-26AWG Crimp Socket | 12
3 | Connector | Molex | 701070001 | 2 pin locking | 6
4 | Contact | Molex | 16020105 | 24-30AWG Pin | 12
5 | Spiral Wrap |  | 0.25" Blue Spiral Wrap | Generic Spiral Wrap - Nylon | 125 in
6 | Cable |  | 2 Wire 26 AWG unshielded - Black/Blue | Generic Cable | 561 in

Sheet: Wiring Table
Wiring Table
Type |  | Harness
Part Number |  | SF-DDC
Description |  | Starfield Data Distribution
# | From | To | Conductor | Conductor PN | Twist With | Gauge | Length | From Contact PN | Notes
1 | C1.1 | C2.2 | CBL1.Blue | 2 Wire 26 AWG unshielded - Black/Blue |  | 26 AWG | 31 in | 47649-000LF
2 | C1.2 | C3.2 | CBL2.Blue | 2 Wire 26 AWG unshielded - Black/Blue |  | 26 AWG | 56 in | 47649-000LF
3 | C1.3 | C4.2 | CBL3.Blue | 2 Wire 26 AWG unshielded - Black/Blue |  | 26 AWG | 81 in | 47649-000LF
4 | C1.4 | C5.2 | CBL4.Blue | 2 Wire 26 AWG unshielded - Black/Blue |  | 26 AWG | 106 in | 47649-000LF
5 | C1.5 | C6.2 | CBL5.Blue | 2 Wire 26 AWG unshielded - Black/Blue |  | 26 AWG | 131 in | 47649-000LF
6 | C1.6 | C7.2 | CBL6.Blue | 2 Wire 26 AWG unshielded - Black/Blue |  | 26 AWG | 156 in | 47649-000LF
7 | C1.7 | C2.1 | CBL1.Black | 2 Wire 26 AWG unshielded - Black/Blue |  | 26 AWG | 31 in | 47649-000LF
8 | C1.8 | C3.1 | CBL2.Black | 2 Wire 26 AWG unshielded - Black/Blue |  | 26 AWG | 56 in | 47649-000LF
9 | C1.9 | C4.1 | CBL3.Black | 2 Wire 26 AWG unshielded - Black/Blue |  | 26 AWG | 81 in | 47649-000LF
10 | C1.10 | C5.1 | CBL4.Black | 2 Wire 26 AWG unshielded - Black/Blue |  | 26 AWG | 106 in | 47649-000LF
11 | C1.11 | C6.1 | CBL5.Black | 2 Wire 26 AWG unshielded - Black/Blue |  | 26 AWG | 131 in | 47649-000LF
12 | C1.12 | C7.1 | CBL6.Black | 2 Wire 26 AWG unshielded - Black/Blue |  | 26 AWG | 156 in | 47649-000LF

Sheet: Cutlist
Cutlist
Type |  | Harness
Part Number |  | SF-DDC
Description |  | Starfield Data Distribution
# | Type | Reference Designator | Manufacturer | Part Number | Color | Gauge | Length | Twisted With
1 | Cable | CBL1 |  | 2 Wire 26 AWG unshielded - Black/Blue | White |  | 31 in
2 | Cable | CBL2 |  | 2 Wire 26 AWG unshielded - Black/Blue | White |  | 56 in
3 | Cable | CBL3 |  | 2 Wire 26 AWG unshielded - Black/Blue | White |  | 81 in
4 | Cable | CBL4 |  | 2 Wire 26 AWG unshielded - Black/Blue | White |  | 106 in
5 | Cable | CBL5 |  | 2 Wire 26 AWG unshielded - Black/Blue | White |  | 131 in
6 | Cable | CBL6 |  | 2 Wire 26 AWG unshielded - Black/Blue | White |  | 156 in

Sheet: Labels
Labels
Type |  | Harness
Part Number |  | SF-DDC
Description |  | Starfield Data Distribution
# | Manufacturer | Part Number | Description | Label Text

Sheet: Connections
Connections
Type |  | Harness
Part Number |  | SF-DDC
Description |  | Starfield Data Distribution
# | From | To | Conductor | Conductor PN | Twist With | Gauge | Length | From Contact PN | To Contact PN | Notes
1 | C1.1 | C2.2 | CBL1.Blue | 2 Wire 26 AWG unshielded - Black/Blue |  | 26 AWG | 31 in | 47649-000LF | 0016020105
2 | C1.2 | C3.2 | CBL2.Blue | 2 Wire 26 AWG unshielded - Black/Blue |  | 26 AWG | 56 in | 47649-000LF | 0016020105
3 | C1.3 | C4.2 | CBL3.Blue | 2 Wire 26 AWG unshielded - Black/Blue |  | 26 AWG | 81 in | 47649-000LF | 0016020105
4 | C1.4 | C5.2 | CBL4.Blue | 2 Wire 26 AWG unshielded - Black/Blue |  | 26 AWG | 106 in | 47649-000LF | 0016020105
5 | C1.5 | C6.2 | CBL5.Blue | 2 Wire 26 AWG unshielded - Black/Blue |  | 26 AWG | 131 in | 47649-000LF | 0016020105
6 | C1.6 | C7.2 | CBL6.Blue | 2 Wire 26 AWG unshielded - Black/Blue |  | 26 AWG | 156 in | 47649-000LF | 0016020105
7 | C1.7 | C2.1 | CBL1.Black | 2 Wire 26 AWG unshielded - Black/Blue |  | 26 AWG | 31 in | 47649-000LF | 0016020105
8 | C1.8 | C3.1 | CBL2.Black | 2 Wire 26 AWG unshielded - Black/Blue |  | 26 AWG | 56 in | 47649-000LF | 0016020105
9 | C1.9 | C4.1 | CBL3.Black | 2 Wire 26 AWG unshielded - Black/Blue |  | 26 AWG | 81 in | 47649-000LF | 0016020105
10 | C1.10 | C5.1 | CBL4.Black | 2 Wire 26 AWG unshielded - Black/Blue |  | 26 AWG | 106 in | 47649-000LF | 0016020105
11 | C1.11 | C6.1 | CBL5.Black | 2 Wire 26 AWG unshielded - Black/Blue |  | 26 AWG | 131 in | 47649-000LF | 0016020105
12 | C1.12 | C7.1 | CBL6.Black | 2 Wire 26 AWG unshielded - Black/Blue |  | 26 AWG | 156 in | 47649-000LF | 0016020105

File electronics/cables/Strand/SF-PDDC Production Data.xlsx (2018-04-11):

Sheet: Bill of Materials
Bill of Materials
Type |  | Harness
Part Number |  | SF-PDDC
Description
Id | Type | Manufacturer | Part Number | Description | Quantity
1 | Cable |  | 2 Wire 18 AWG unshielded - Red/Black | Generic Cable | ≥ 20.5 ft
2 | Connector | Molex, LLC | 50579004 | CONN HOUSING 4POS .100 SINGLE | 11
3 | Contact |  | 28-26 AWG Pin Crimp | Generic Contact | 42
4 | Heat Shrink |  | Generic Heat Shrink | Generic Heat Shrink | 13
5 | Sleeving |  | Black Sleeving | Generic Sleeving - Kevlar, Braided | 259 in
6 | Sleeving |  | Black Sleeving | Generic Sleeving - Kevlar
7 | Sleeving |  | White Sleeving | Generic Sleeving - Kevlar, Braided | 2 ft
8 | Wire |  | UL1061 28 AWG Black | UL 1061 rated 28 AWG Black SR-PVC Hook-up wire | ≥ 45 in
9 | Wire |  | UL1061 28 AWG Blue | UL 1061 rated 28 AWG Blue SR-PVC Hook-up wire | ≥ 288 in
10 | Wire |  | UL1061 28 AWG Red | UL 1061 rated 28 AWG Red SR-PVC Hook-up wire | ≥ 33 in
11 | Connector | AMP | 282104-1 | AMP SUPERSEAL 1.5 SERIES 2P CA | 1
12 | Contact | AMP | 282109-1 | AMP MINI MIC TAB CONTACT | 2
13 | Wire Seal | AMP | 281934-2 | Amp SuperSeal 1.5 Single Wire Seal | 2
14 | Connector | Molex | 50-57-9402 | 2 Position Rectangular Housing Connector Receptacle Black 0.100" (2.54mm) | 2
15 | Contact | Molex | 16-02-0069 | Socket Contact Tin 24-30 AWG Crimp | 4

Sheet: Wiring Table
Wiring Table
Type |  | Harness
Part Number |  | SF-PDDC
Description
# | From | To | Conductor | Conductor PN | Twist With | Gauge | Length | From Contact PN | Notes
1 | C1.1 | S2 | CBL11.Black | 2 Wire 18 AWG unshielded - Red/Black |  | 18 AWG | ≥ 6 in | 282109-1
2 | C1.2 | S1 | CBL11.Red | 2 Wire 18 AWG unshielded - Red/Black |  | 18 AWG | ≥ 6 in | 282109-1
3 | C2.1 | S22 | W35.Black | UL1061 28 AWG Black |  | 28 AWG | ≥ 6 in | 16-02-0069
4 | C2.2 | C14.4 | W10.Blue | UL1061 28 AWG Blue |  | 28 AWG | ≥ 9 in | 16-02-0069
5 | C3.1 | S2 | W12.Black | UL1061 28 AWG Black |  | 28 AWG | 6 in | 16-02-0069
6 | C3.2 | C4.4 | W11.Blue | UL1061 28 AWG Blue |  | 28 AWG | ≥ 9 in | 16-02-0069
7 | C4.1 | S2 | W13.Black | UL1061 28 AWG Black |  | 28 AWG | ≥ 3 in | 28-26 AWG Pin Crimp
8 | C4.2 | S1 | W24.Red | UL1061 28 AWG Red |  | 28 AWG | ≥ 3 in | 28-26 AWG Pin Crimp
9 | C4.3 | C5.4 | W1.Blue | UL1061 28 AWG Blue |  | 28 AWG | ≥ 30 in | 28-26 AWG Pin Crimp
10 | C5.1 | S4 | W14.Black | UL1061 28 AWG Black |  | 28 AWG | ≥ 3 in | 28-26 AWG Pin Crimp
11 | C5.2 | S3 | W25.Red | UL1061 28 AWG Red |  | 28 AWG | ≥ 3 in | 28-26 AWG Pin Crimp
12 | C5.3 | C6.4 | W3.Blue | UL1061 28 AWG Blue |  | 28 AWG | ≥ 30 in | 28-26 AWG Pin Crimp
13 | C6.1 | S6 | W15.Black | UL1061 28 AWG Black |  | 28 AWG | ≥ 3 in | 28-26 AWG Pin Crimp
14 | C6.2 | S5 | W26.Red | UL1061 28 AWG Red |  | 28 AWG | ≥ 3 in | 28-26 AWG Pin Crimp
15 | C6.3 | C7.4 | W4.Blue | UL1061 28 AWG Blue |  | 28 AWG | ≥ 30 in | 28-26 AWG Pin Crimp
16 | C7.1 | S8 | W16.Black | UL1061 28 AWG Black |  | 28 AWG | ≥ 3 in | 28-26 AWG Pin Crimp
17 | C7.2 | S7 | W27.Red | UL1061 28 AWG Red |  | 28 AWG | ≥ 3 in | 28-26 AWG Pin Crimp
18 | C7.3 | C8.4 | W5.Blue | UL1061 28 AWG Blue |  | 28 AWG | ≥ 30 in | 28-26 AWG Pin Crimp
19 | C8.1 | S10 | W17.Black | UL1061 28 AWG Black |  | 28 AWG | ≥ 3 in | 28-26 AWG Pin Crimp
20 | C8.2 | S9 | W28.Red | UL1061 28 AWG Red |  | 28 AWG | ≥ 3 in | 28-26 AWG Pin Crimp
21 | C8.3 | C9.4 | W6.Blue | UL1061 28 AWG Blue |  | 28 AWG | ≥ 30 in | 28-26 AWG Pin Crimp
22 | C9.1 | S12 | W18.Black | UL1061 28 AWG Black |  | 28 AWG | ≥ 3 in | 28-26 AWG Pin Crimp
23 | C9.2 | S11 | W29.Red | UL1061 28 AWG Red |  | 28 AWG | ≥ 3 in | 28-26 AWG Pin Crimp
24 | C10.1 | S14 | W19.Black | UL1061 28 AWG Black |  | 28 AWG | ≥ 3 in | 28-26 AWG Pin Crimp
25 | C10.2 | S13 | W30.Red | UL1061 28 AWG Red |  | 28 AWG | ≥ 3 in | 28-26 AWG Pin Crimp
26 | C11.1 | S16 | W20.Black | UL1061 28 AWG Black |  | 28 AWG | ≥ 3 in | 28-26 AWG Pin Crimp
27 | C11.2 | S15 | W34.Red | UL1061 28 AWG Red |  | 28 AWG | ≥ 3 in | 28-26 AWG Pin Crimp
28 | C11.3 | C10.4 | W9.Blue | UL1061 28 AWG Blue |  | 28 AWG | ≥ 30 in | 28-26 AWG Pin Crimp
29 | C12.1 | S18 | W21.Black | UL1061 28 AWG Black |  | 28 AWG | ≥ 3 in | 28-26 AWG Pin Crimp
30 | C12.2 | S17 | W31.Red | UL1061 28 AWG Red |  | 28 AWG | ≥ 3 in | 28-26 AWG Pin Crimp
31 | C12.3 | C11.4 | W8.Blue | UL1061 28 AWG Blue |  | 28 AWG | ≥ 30 in | 28-26 AWG Pin Crimp
32 | C13.1 | S20 | W22.Black | UL1061 28 AWG Black |  | 28 AWG | ≥ 3 in | 28-26 AWG Pin Crimp
33 | C13.2 | S19 | W32.Red | UL1061 28 AWG Red |  | 28 AWG | ≥ 3 in | 28-26 AWG Pin Crimp
34 | C13.3 | C12.4 | W2.Blue | UL1061 28 AWG Blue |  | 28 AWG | ≥ 30 in | 28-26 AWG Pin Crimp
35 | C14.1 | S22 | W23.Black | UL1061 28 AWG Black |  | 28 AWG | ≥ 3 in | 28-26 AWG Pin Crimp
36 | C14.2 | S21 | W33.Red | UL1061 28 AWG Red |  | 28 AWG | ≥ 3 in | 28-26 AWG Pin Crimp
37 | C14.3 | C13.4 | W7.Blue | UL1061 28 AWG Blue |  | 28 AWG | ≥ 30 in | 28-26 AWG Pin Crimp
38 | S1 | S3 | CBL1.Red | 2 Wire 18 AWG unshielded - Red/Black |  | 18 AWG | ≥ 2 ft
39 | S2 | S4 | CBL1.Black | 2 Wire 18 AWG unshielded - Red/Black |  | 18 AWG | ≥ 2 ft
40 | S3 | S5 | CBL2.Red | 2 Wire 18 AWG unshielded - Red/Black |  | 18 AWG | ≥ 2 ft
41 | S4 | S6 | CBL2.Black | 2 Wire 18 AWG unshielded - Red/Black |  | 18 AWG | ≥ 2 ft
42 | S5 | S7 | CBL3.Red | 2 Wire 18 AWG unshielded - Red/Black |  | 18 AWG | ≥ 2 ft
43 | S6 | S8 | CBL3.Black | 2 Wire 18 AWG unshielded - Red/Black |  | 18 AWG | ≥ 2 ft
44 | S7 | S9 | CBL4.Red | 2 Wire 18 AWG unshielded - Red/Black |  | 18 AWG | ≥ 2 ft
45 | S8 | S10 | CBL4.Black | 2 Wire 18 AWG unshielded - Red/Black |  | 18 AWG | ≥ 2 ft
46 | S9 | S11 | CBL5.Red | 2 Wire 18 AWG unshielded - Red/Black |  | 18 AWG | ≥ 2 ft
47 | S10 | S12 | CBL5.Black | 2 Wire 18 AWG unshielded - Red/Black |  | 18 AWG | ≥ 2 ft
48 | S11 | S13 | CBL6.Red | 2 Wire 18 AWG unshielded - Red/Black |  | 18 AWG | ≥ 2 ft
49 | S13 | S15 | CBL7.Red | 2 Wire 18 AWG unshielded - Red/Black |  | 18 AWG | ≥ 2 ft
50 | S14 | S12 | CBL6.Black | 2 Wire 18 AWG unshielded - Red/Black |  | 18 AWG | ≥ 2 ft
51 | S14 | S16 | CBL7.Black | 2 Wire 18 AWG unshielded - Red/Black |  | 18 AWG | ≥ 2 ft
52 | S15 | S17 | CBL8.Red | 2 Wire 18 AWG unshielded - Red/Black |  | 18 AWG | ≥ 2 ft
53 | S16 | S18 | CBL8.Black | 2 Wire 18 AWG unshielded - Red/Black |  | 18 AWG | ≥ 2 ft
54 | S17 | S19 | CBL9.Red | 2 Wire 18 AWG unshielded - Red/Black |  | 18 AWG | ≥ 2 ft
55 | S18 | S20 | CBL9.Black | 2 Wire 18 AWG unshielded - Red/Black |  | 18 AWG | ≥ 2 ft
56 | S19 | S21 | CBL10.Red | 2 Wire 18 AWG unshielded - Red/Black |  | 18 AWG | ≥ 2 ft
57 | S20 | S22 | CBL10.Black | 2 Wire 18 AWG unshielded - Red/Black |  | 18 AWG | ≥ 2 ft

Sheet: Cutlist
Cutlist
Type |  | Harness
Part Number |  | SF-PDDC
Description
# | Type | Reference Designator | Manufacturer | Part Number | Color | Gauge | Length | Twisted With
1 | Cable | CBL1 |  | 2 Wire 18 AWG unshielded - Red/Black | White |  | ≥ 2 ft
2 | Cable | CBL2 |  | 2 Wire 18 AWG unshielded - Red/Black | White |  | ≥ 2 ft
3 | Cable | CBL3 |  | 2 Wire 18 AWG unshielded - Red/Black | White |  | ≥ 2 ft
4 | Cable | CBL4 |  | 2 Wire 18 AWG unshielded - Red/Black | White |  | ≥ 2 ft
5 | Cable | CBL5 |  | 2 Wire 18 AWG unshielded - Red/Black | White |  | ≥ 2 ft
6 | Cable | CBL6 |  | 2 Wire 18 AWG unshielded - Red/Black | White |  | ≥ 2 ft
7 | Cable | CBL7 |  | 2 Wire 18 AWG unshielded - Red/Black | White |  | ≥ 2 ft
8 | Cable | CBL8 |  | 2 Wire 18 AWG unshielded - Red/Black | White |  | ≥ 2 ft
9 | Cable | CBL9 |  | 2 Wire 18 AWG unshielded - Red/Black | White |  | ≥ 2 ft
10 | Cable | CBL10 |  | 2 Wire 18 AWG unshielded - Red/Black | White |  | ≥ 2 ft
11 | Cable | CBL11 |  | 2 Wire 18 AWG unshielded - Red/Black | White |  | ≥ 6 in
12 | Wire | W1 |  | UL1061 28 AWG Blue | Blue | 28 AWG | ≥ 30 in
13 | Wire | W2 |  | UL1061 28 AWG Blue | Blue | 28 AWG | ≥ 30 in
14 | Wire | W3 |  | UL1061 28 AWG Blue | Blue | 28 AWG | ≥ 30 in
15 | Wire | W4 |  | UL1061 28 AWG Blue | Blue | 28 AWG | ≥ 30 in
16 | Wire | W5 |  | UL1061 28 AWG Blue | Blue | 28 AWG | ≥ 30 in
17 | Wire | W6 |  | UL1061 28 AWG Blue | Blue | 28 AWG | ≥ 30 in
18 | Wire | W7 |  | UL1061 28 AWG Blue | Blue | 28 AWG | ≥ 30 in
19 | Wire | W8 |  | UL1061 28 AWG Blue | Blue | 28 AWG | ≥ 30 in
20 | Wire | W9 |  | UL1061 28 AWG Blue | Blue | 28 AWG | ≥ 30 in
21 | Wire | W10 |  | UL1061 28 AWG Blue | Blue | 28 AWG | ≥ 9 in
22 | Wire | W11 |  | UL1061 28 AWG Blue | Blue | 28 AWG | ≥ 9 in
23 | Wire | W12 |  | UL1061 28 AWG Black | Black | 28 AWG | 6 in
24 | Wire | W13 |  | UL1061 28 AWG Black | Black | 28 AWG | ≥ 3 in
25 | Wire | W14 |  | UL1061 28 AWG Black | Black | 28 AWG | ≥ 3 in
26 | Wire | W15 |  | UL1061 28 AWG Black | Black | 28 AWG | ≥ 3 in
27 | Wire | W16 |  | UL1061 28 AWG Black | Black | 28 AWG | ≥ 3 in
28 | Wire | W17 |  | UL1061 28 AWG Black | Black | 28 AWG | ≥ 3 in
29 | Wire | W18 |  | UL1061 28 AWG Black | Black | 28 AWG | ≥ 3 in
30 | Wire | W19 |  | UL1061 28 AWG Black | Black | 28 AWG | ≥ 3 in
31 | Wire | W20 |  | UL1061 28 AWG Black | Black | 28 AWG | ≥ 3 in
32 | Wire | W21 |  | UL1061 28 AWG Black | Black | 28 AWG | ≥ 3 in
33 | Wire | W22 |  | UL1061 28 AWG Black | Black | 28 AWG | ≥ 3 in
34 | Wire | W23 |  | UL1061 28 AWG Black | Black | 28 AWG | ≥ 3 in
35 | Wire | W24 |  | UL1061 28 AWG Red | Red | 28 AWG | ≥ 3 in
36 | Wire | W25 |  | UL1061 28 AWG Red | Red | 28 AWG | ≥ 3 in
37 | Wire | W26 |  | UL1061 28 AWG Red | Red | 28 AWG | ≥ 3 in
38 | Wire | W27 |  | UL1061 28 AWG Red | Red | 28 AWG | ≥ 3 in
39 | Wire | W28 |  | UL1061 28 AWG Red | Red | 28 AWG | ≥ 3 in
40 | Wire | W29 |  | UL1061 28 AWG Red | Red | 28 AWG | ≥ 3 in
41 | Wire | W30 |  | UL1061 28 AWG Red | Red | 28 AWG | ≥ 3 in
42 | Wire | W31 |  | UL1061 28 AWG Red | Red | 28 AWG | ≥ 3 in
43 | Wire | W32 |  | UL1061 28 AWG Red | Red | 28 AWG | ≥ 3 in
44 | Wire | W33 |  | UL1061 28 AWG Red | Red | 28 AWG | ≥ 3 in
45 | Wire | W34 |  | UL1061 28 AWG Red | Red | 28 AWG | ≥ 3 in
46 | Wire | W35 |  | UL1061 28 AWG Black | Black | 28 AWG | ≥ 6 in

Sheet: Labels
Labels
Type |  | Harness
Part Number |  | SF-PDDC
Description
# | Manufacturer | Part Number | Description | Label Text

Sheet: Connections
Connections
Type |  | Harness
Part Number |  | SF-PDDC
Description
# | From | To | Conductor | Conductor PN | Twist With | Gauge | Length | From Contact PN | To Contact PN | Notes
1 | C1.1 | S2 | CBL11.Black | 2 Wire 18 AWG unshielded - Red/Black |  | 18 AWG | ≥ 6 in | 282109-1
2 | C1.2 | S1 | CBL11.Red | 2 Wire 18 AWG unshielded - Red/Black |  | 18 AWG | ≥ 6 in | 282109-1
3 | C2.1 | S22 | W35.Black | UL1061 28 AWG Black |  | 28 AWG | ≥ 6 in | 16-02-0069
4 | C2.2 | C14.4 | W10.Blue | UL1061 28 AWG Blue |  | 28 AWG | ≥ 9 in | 16-02-0069 | 28-26 AWG Pin Crimp
5 | C3.1 | S2 | W12.Black | UL1061 28 AWG Black |  | 28 AWG | 6 in | 16-02-0069
6 | C3.2 | C4.4 | W11.Blue | UL1061 28 AWG Blue |  | 28 AWG | ≥ 9 in | 16-02-0069 | 28-26 AWG Pin Crimp
7 | C4.1 | S2 | W13.Black | UL1061 28 AWG Black |  | 28 AWG | ≥ 3 in | 28-26 AWG Pin Crimp
8 | C4.2 | S1 | W24.Red | UL1061 28 AWG Red |  | 28 AWG | ≥ 3 in | 28-26 AWG Pin Crimp
9 | C4.3 | C5.4 | W1.Blue | UL1061 28 AWG Blue |  | 28 AWG | ≥ 30 in | 28-26 AWG Pin Crimp | 28-26 AWG Pin Crimp
10 | C5.1 | S4 | W14.Black | UL1061 28 AWG Black |  | 28 AWG | ≥ 3 in | 28-26 AWG Pin Crimp
11 | C5.2 | S3 | W25.Red | UL1061 28 AWG Red |  | 28 AWG | ≥ 3 in | 28-26 AWG Pin Crimp
12 | C5.3 | C6.4 | W3.Blue | UL1061 28 AWG Blue |  | 28 AWG | ≥ 30 in | 28-26 AWG Pin Crimp | 28-26 AWG Pin Crimp
13 | C6.1 | S6 | W15.Black | UL1061 28 AWG Black |  | 28 AWG | ≥ 3 in | 28-26 AWG Pin Crimp
14 | C6.2 | S5 | W26.Red | UL1061 28 AWG Red |  | 28 AWG | ≥ 3 in | 28-26 AWG Pin Crimp
15 | C6.3 | C7.4 | W4.Blue | UL1061 28 AWG Blue |  | 28 AWG | ≥ 30 in | 28-26 AWG Pin Crimp | 28-26 AWG Pin Crimp
16 | C7.1 | S8 | W16.Black | UL1061 28 AWG Black |  | 28 AWG | ≥ 3 in | 28-26 AWG Pin Crimp
17 | C7.2 | S7 | W27.Red | UL1061 28 AWG Red |  | 28 AWG | ≥ 3 in | 28-26 AWG Pin Crimp
18 | C7.3 | C8.4 | W5.Blue | UL1061 28 AWG Blue |  | 28 AWG | ≥ 30 in | 28-26 AWG Pin Crimp | 28-26 AWG Pin Crimp
19 | C8.1 | S10 | W17.Black | UL1061 28 AWG Black |  | 28 AWG | ≥ 3 in | 28-26 AWG Pin Crimp
20 | C8.2 | S9 | W28.Red | UL1061 28 AWG Red |  | 28 AWG | ≥ 3 in | 28-26 AWG Pin Crimp
21 | C8.3 | C9.4 | W6.Blue | UL1061 28 AWG Blue |  | 28 AWG | ≥ 30 in | 28-26 AWG Pin Crimp | 28-26 AWG Pin Crimp
22 | C9.1 | S12 | W18.Black | UL1061 28 AWG Black |  | 28 AWG | ≥ 3 in | 28-26 AWG Pin Crimp
23 | C9.2 | S11 | W29.Red | UL1061 28 AWG Red |  | 28 AWG | ≥ 3 in | 28-26 AWG Pin Crimp
24 | C10.1 | S14 | W19.Black | UL1061 28 AWG Black |  | 28 AWG | ≥ 3 in | 28-26 AWG Pin Crimp
25 | C10.2 | S13 | W30.Red | UL1061 28 AWG Red |  | 28 AWG | ≥ 3 in | 28-26 AWG Pin Crimp
26 | C11.1 | S16 | W20.Black | UL1061 28 AWG Black |  | 28 AWG | ≥ 3 in | 28-26 AWG Pin Crimp
27 | C11.2 | S15 | W34.Red | UL1061 28 AWG Red |  | 28 AWG | ≥ 3 in | 28-26 AWG Pin Crimp
28 | C11.3 | C10.4 | W9.Blue | UL1061 28 AWG Blue |  | 28 AWG | ≥ 30 in | 28-26 AWG Pin Crimp | 28-26 AWG Pin Crimp
29 | C12.1 | S18 | W21.Black | UL1061 28 AWG Black |  | 28 AWG | ≥ 3 in | 28-26 AWG Pin Crimp
30 | C12.2 | S17 | W31.Red | UL1061 28 AWG Red |  | 28 AWG | ≥ 3 in | 28-26 AWG Pin Crimp
31 | C12.3 | C11.4 | W8.Blue | UL1061 28 AWG Blue |  | 28 AWG | ≥ 30 in | 28-26 AWG Pin Crimp | 28-26 AWG Pin Crimp
32 | C13.1 | S20 | W22.Black | UL1061 28 AWG Black |  | 28 AWG | ≥ 3 in | 28-26 AWG Pin Crimp
33 | C13.2 | S19 | W32.Red | UL1061 28 AWG Red |  | 28 AWG | ≥ 3 in | 28-26 AWG Pin Crimp
34 | C13.3 | C12.4 | W2.Blue | UL1061 28 AWG Blue |  | 28 AWG | ≥ 30 in | 28-26 AWG Pin Crimp | 28-26 AWG Pin Crimp
35 | C14.1 | S22 | W23.Black | UL1061 28 AWG Black |  | 28 AWG | ≥ 3 in | 28-26 AWG Pin Crimp
36 | C14.2 | S21 | W33.Red | UL1061 28 AWG Red |  | 28 AWG | ≥ 3 in | 28-26 AWG Pin Crimp
37 | C14.3 | C13.4 | W7.Blue | UL1061 28 AWG Blue |  | 28 AWG | ≥ 30 in | 28-26 AWG Pin Crimp | 28-26 AWG Pin Crimp
38 | S1 | S3 | CBL1.Red | 2 Wire 18 AWG unshielded - Red/Black |  | 18 AWG | ≥ 2 ft
39 | S2 | S4 | CBL1.Black | 2 Wire 18 AWG unshielded - Red/Black |  | 18 AWG | ≥ 2 ft
40 | S3 | S5 | CBL2.Red | 2 Wire 18 AWG unshielded - Red/Black |  | 18 AWG | ≥ 2 ft
41 | S4 | S6 | CBL2.Black | 2 Wire 18 AWG unshielded - Red/Black |  | 18 AWG | ≥ 2 ft
42 | S5 | S7 | CBL3.Red | 2 Wire 18 AWG unshielded - Red/Black |  | 18 AWG | ≥ 2 ft
43 | S6 | S8 | CBL3.Black | 2 Wire 18 AWG unshielded - Red/Black |  | 18 AWG | ≥ 2 ft
44 | S7 | S9 | CBL4.Red | 2 Wire 18 AWG unshielded - Red/Black |  | 18 AWG | ≥ 2 ft
45 | S8 | S10 | CBL4.Black | 2 Wire 18 AWG unshielded - Red/Black |  | 18 AWG | ≥ 2 ft
46 | S9 | S11 | CBL5.Red | 2 Wire 18 AWG unshielded - Red/Black |  | 18 AWG | ≥ 2 ft
47 | S10 | S12 | CBL5.Black | 2 Wire 18 AWG unshielded - Red/Black |  | 18 AWG | ≥ 2 ft
48 | S11 | S13 | CBL6.Red | 2 Wire 18 AWG unshielded - Red/Black |  | 18 AWG | ≥ 2 ft
49 | S13 | S15 | CBL7.Red | 2 Wire 18 AWG unshielded - Red/Black |  | 18 AWG | ≥ 2 ft
50 | S14 | S12 | CBL6.Black | 2 Wire 18 AWG unshielded - Red/Black |  | 18 AWG | ≥ 2 ft
51 | S14 | S16 | CBL7.Black | 2 Wire 18 AWG unshielded - Red/Black |  | 18 AWG | ≥ 2 ft
52 | S15 | S17 | CBL8.Red | 2 Wire 18 AWG unshielded - Red/Black |  | 18 AWG | ≥ 2 ft
53 | S16 | S18 | CBL8.Black | 2 Wire 18 AWG unshielded - Red/Black |  | 18 AWG | ≥ 2 ft
54 | S17 | S19 | CBL9.Red | 2 Wire 18 AWG unshielded - Red/Black |  | 18 AWG | ≥ 2 ft
55 | S18 | S20 | CBL9.Black | 2 Wire 18 AWG unshielded - Red/Black |  | 18 AWG | ≥ 2 ft
56 | S19 | S21 | CBL10.Red | 2 Wire 18 AWG unshielded - Red/Black |  | 18 AWG | ≥ 2 ft
57 | S20 | S22 | CBL10.Black | 2 Wire 18 AWG unshielded - Red/Black |  | 18 AWG | ≥ 2 ft

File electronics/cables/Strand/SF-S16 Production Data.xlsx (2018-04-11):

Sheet: Bill of Materials
Bill of Materials
Type |  | Harness
Part Number |  | SF-S16
Description |  | short Starfield strand cable
Id | Type | Manufacturer | Part Number | Description | Quantity
1 | Cable | MicroFlex Wire and Cable (http://microflexwire.com/) | BN42840FEPUSIL | 4 Conductor Twisted with Kevlar Colors | 16 in
2 | Connector | JST | ZHR-04 | 4 circuit ZH connector housing, white | 1
3 | Connector | Molex, LLC | 50579004 | CONN HOUSING 4POS .100 SINGLE | 1

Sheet: Wiring Table
Wiring Table
Type |  | Harness
Part Number |  | SF-S16
Description |  | short Starfield strand cable
# | From | To | Conductor | Conductor PN | Twist With | Gauge | Length | From Contact PN | Notes
1 | C1.1 | C2.1 | CBL1.Green | BN42840FEPUSIL |  | 28 AWG | 16 in
2 | C1.2 | C2.2 | CBL1.Orange | BN42840FEPUSIL |  | 28 AWG | 16 in
3 | C1.3 | C2.3 | CBL1.Blue | BN42840FEPUSIL |  | 28 AWG | 16 in
4 | C1.4 | C2.4 | CBL1.White | BN42840FEPUSIL |  | 28 AWG | 16 in

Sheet: Cutlist
Cutlist
Type |  | Harness
Part Number |  | SF-S16
Description |  | short Starfield strand cable
# | Type | Reference Designator | Manufacturer | Part Number | Color | Gauge | Length | Twisted With
1 | Cable | CBL1 | MicroFlex Wire and Cable (http://microflexwire.com/) | BN42840FEPUSIL | Black |  | 16 in

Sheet: Labels
Labels
Type |  | Harness
Part Number |  | SF-S16
Description |  | short Starfield strand cable
# | Manufacturer | Part Number | Description | Label Text

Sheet: Connections
Connections
Type |  | Harness
Part Number |  | SF-S16
Description |  | short Starfield strand cable
# | From | To | Conductor | Conductor PN | Twist With | Gauge | Length | From Contact PN | To Contact PN | Notes
1 | C1.1 | C2.1 | CBL1.Green | BN42840FEPUSIL |  | 28 AWG | 16 in
2 | C1.2 | C2.2 | CBL1.Orange | BN42840FEPUSIL |  | 28 AWG | 16 in
3 | C1.3 | C2.3 | CBL1.Blue | BN42840FEPUSIL |  | 28 AWG | 16 in
4 | C1.4 | C2.4 | CBL1.White | BN42840FEPUSIL |  | 28 AWG | 16 in

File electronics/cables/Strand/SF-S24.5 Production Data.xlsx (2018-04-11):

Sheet: Bill of Materials
Bill of Materials
Type |  | Harness
Part Number |  | SF-S24.5
Description |  | 2' .5" Starfield strand cable
Id | Type | Manufacturer | Part Number | Description | Quantity
1 | Cable | MicroFlex Wire and Cable (http://microflexwire.com/) | BN42840FEPUSIL | 4 Conductor Twisted with Kevlar Colors | 24.5 in
2 | Connector | JST | ZHR-04 | 4 circuit ZH connector housing, white | 2
3 | Contact | JST | SZH-003T-P0.5 | 32-28 awg zh crimp pin | 8

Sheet: Wiring Table
Wiring Table
Type |  | Harness
Part Number |  | SF-S24.5
Description |  | 2' .5" Starfield strand cable
# | From | To | Conductor | Conductor PN | Twist With | Gauge | Length | From Contact PN | Notes
1 | C1.1 | C2.1 | CBL1.Green | BN42840FEPUSIL |  | 28 AWG | 24.5 in | SZH-003T-P0.5
2 | C1.2 | C2.2 | CBL1.Orange | BN42840FEPUSIL |  | 28 AWG | 24.5 in | SZH-003T-P0.5
3 | C1.3 | C2.3 | CBL1.Blue | BN42840FEPUSIL |  | 28 AWG | 24.5 in | SZH-003T-P0.5
4 | C1.4 | C2.4 | CBL1.White | BN42840FEPUSIL |  | 28 AWG | 24.5 in | SZH-003T-P0.5

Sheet: Cutlist
Cutlist
Type |  | Harness
Part Number |  | SF-S24.5
Description |  | 2' .5" Starfield strand cable
# | Type | Reference Designator | Manufacturer | Part Number | Color | Gauge | Length | Twisted With
1 | Cable | CBL1 | MicroFlex Wire and Cable (http://microflexwire.com/) | BN42840FEPUSIL | Black |  | 24.5 in

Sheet: Labels
Labels
Type |  | Harness
Part Number |  | SF-S24.5
Description |  | 2' .5" Starfield strand cable
# | Manufacturer | Part Number | Description | Label Text

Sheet: Connections
Connections
Type |  | Harness
Part Number |  | SF-S24.5
Description |  | 2' .5" Starfield strand cable
# | From | To | Conductor | Conductor PN | Twist With | Gauge | Length | From Contact PN | To Contact PN | Notes
1 | C1.1 | C2.1 | CBL1.Green | BN42840FEPUSIL |  | 28 AWG | 24.5 in | SZH-003T-P0.5 | SZH-003T-P0.5
2 | C1.2 | C2.2 | CBL1.Orange | BN42840FEPUSIL |  | 28 AWG | 24.5 in | SZH-003T-P0.5 | SZH-003T-P0.5
3 | C1.3 | C2.3 | CBL1.Blue | BN42840FEPUSIL |  | 28 AWG | 24.5 in | SZH-003T-P0.5 | SZH-003T-P0.5
4 | C1.4 | C2.4 | CBL1.White | BN42840FEPUSIL |  | 28 AWG | 24.5 in | SZH-003T-P0.5 | SZH-003T-P0.5

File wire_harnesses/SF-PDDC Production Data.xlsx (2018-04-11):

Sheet: Bill of Materials
Bill of Materials
Type |  | Harness
Part Number |  | SF-PDDC
Description
Item | Type | Manufacturer | Part Number | Quantity | Usage
1 | Cable |  | 2 Wire 18 AWG unshielded - Red/Black | ≥ 20.5 ft | CBL1, CBL2, CBL3, CBL4, CBL5, CBL6, CBL7, CBL8, CBL9, CBL10, CBL11
2 | Connector |  | 2 Cavity | 3 | C1, C2, C3
3 | Connector | Molex, LLC | 50579004 | 11 | C4, C5, C6, C7, C8, C9, C10, C11, C12, C13, C14
4 | Contact |  | 28-26 AWG Pin Crimp | 42 | See Wiring Table
5 | Heat Shrink |  | Generic Heat Shrink | 13 | C4, C2, C3, C5, C6, C7, C8, C9, C10, C11, C12, C13, C14
6 | Sleeving |  | Black Sleeving |  | See Drawing
7 | Sleeving |  | Black Sleeving | 259 in | See Drawing
8 | Sleeving |  | White Sleeving | 2 ft | See Drawing
9 | Splice |  | Generic Splice | 22 | S2, S1, S4, S3, S6, S5, S8, S7, S10, S9, S12, S11, S13, S14, S16, S15, S18, S17, S20, S19, S22, S21
10 | Wire |  | UL1061 28 AWG Black | ≥ 45 in | W12, W13, W14, W15, W16, W17, W18, W19, W20, W21, W22, W23, W35
11 | Wire |  | UL1061 28 AWG Blue | ≥ 288 in | W1, W2, W3, W4, W5, W6, W7, W8, W9, W10, W11
12 | Wire |  | UL1061 28 AWG Red | ≥ 33 in | W24, W25, W26, W27, W28, W29, W30, W31, W32, W33, W34

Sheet: Wire & Cable Cutlist
Wire & Cable Cutlist
Type |  | Harness
Part Number |  | SF-PDDC
Description
# | Type | Reference Designator | Manufacturer | Part Number | Gauge | Color | Length | Twisted With
1 | Cable | CBL1 |  | 2 Wire 18 AWG unshielded - Red/Black |  | White | ≥ 2 ft
2 | Cable | CBL2 |  | 2 Wire 18 AWG unshielded - Red/Black |  | White | ≥ 2 ft
3 | Cable | CBL3 |  | 2 Wire 18 AWG unshielded - Red/Black |  | White | ≥ 2 ft
4 | Cable | CBL4 |  | 2 Wire 18 AWG unshielded - Red/Black |  | White | ≥ 2 ft
5 | Cable | CBL5 |  | 2 Wire 18 AWG unshielded - Red/Black |  | White | ≥ 2 ft
6 | Cable | CBL6 |  | 2 Wire 18 AWG unshielded - Red/Black |  | White | ≥ 2 ft
7 | Cable | CBL7 |  | 2 Wire 18 AWG unshielded - Red/Black |  | White | ≥ 2 ft
8 | Cable | CBL8 |  | 2 Wire 18 AWG unshielded - Red/Black |  | White | ≥ 2 ft
9 | Cable | CBL9 |  | 2 Wire 18 AWG unshielded - Red/Black |  | White | ≥ 2 ft
10 | Cable | CBL10 |  | 2 Wire 18 AWG unshielded - Red/Black |  | White | ≥ 2 ft
11 | Cable | CBL11 |  | 2 Wire 18 AWG unshielded - Red/Black |  | White | ≥ 6 in
12 | Wire | W1 |  | UL1061 28 AWG Blue | 28 AWG | Blue | ≥ 30 in
13 | Wire | W2 |  | UL1061 28 AWG Blue | 28 AWG | Blue | ≥ 30 in
14 | Wire | W3 |  | UL1061 28 AWG Blue | 28 AWG | Blue | ≥ 30 in
15 | Wire | W4 |  | UL1061 28 AWG Blue | 28 AWG | Blue | ≥ 30 in
16 | Wire | W5 |  | UL1061 28 AWG Blue | 28 AWG | Blue | ≥ 30 in
17 | Wire | W6 |  | UL1061 28 AWG Blue | 28 AWG | Blue | ≥ 30 in
18 | Wire | W7 |  | UL1061 28 AWG Blue | 28 AWG | Blue | ≥ 30 in
19 | Wire | W8 |  | UL1061 28 AWG Blue | 28 AWG | Blue | ≥ 30 in
20 | Wire | W9 |  | UL1061 28 AWG Blue | 28 AWG | Blue | ≥ 30 in
21 | Wire | W10 |  | UL1061 28 AWG Blue | 28 AWG | Blue | ≥ 9 in
22 | Wire | W11 |  | UL1061 28 AWG Blue | 28 AWG | Blue | ≥ 9 in
23 | Wire | W12 |  | UL1061 28 AWG Black | 28 AWG | Black | 6 in
24 | Wire | W13 |  | UL1061 28 AWG Black | 28 AWG | Black | ≥ 3 in
25 | Wire | W14 |  | UL1061 28 AWG Black | 28 AWG | Black | ≥ 3 in
26 | Wire | W15 |  | UL1061 28 AWG Black | 28 AWG | Black | ≥ 3 in
27 | Wire | W16 |  | UL1061 28 AWG Black | 28 AWG | Black | ≥ 3 in
28 | Wire | W17 |  | UL1061 28 AWG Black | 28 AWG | Black | ≥ 3 in
29 | Wire | W18 |  | UL1061 28 AWG Black | 28 AWG | Black | ≥ 3 in
30 | Wire | W19 |  | UL1061 28 AWG Black | 28 AWG | Black | ≥ 3 in
31 | Wire | W20 |  | UL1061 28 AWG Black | 28 AWG | Black | ≥ 3 in
32 | Wire | W21 |  | UL1061 28 AWG Black | 28 AWG | Black | ≥ 3 in
33 | Wire | W22 |  | UL1061 28 AWG Black | 28 AWG | Black | ≥ 3 in
34 | Wire | W23 |  | UL1061 28 AWG Black | 28 AWG | Black | ≥ 3 in
35 | Wire | W24 |  | UL1061 28 AWG Red | 28 AWG | Red | ≥ 3 in
36 | Wire | W25 |  | UL1061 28 AWG Red | 28 AWG | Red | ≥ 3 in
37 | Wire | W26 |  | UL1061 28 AWG Red | 28 AWG | Red | ≥ 3 in
38 | Wire | W27 |  | UL1061 28 AWG Red | 28 AWG | Red | ≥ 3 in
39 | Wire | W28 |  | UL1061 28 AWG Red | 28 AWG | Red | ≥ 3 in
40 | Wire | W29 |  | UL1061 28 AWG Red | 28 AWG | Red | ≥ 3 in
41 | Wire | W30 |  | UL1061 28 AWG Red | 28 AWG | Red | ≥ 3 in
42 | Wire | W31 |  | UL1061 28 AWG Red | 28 AWG | Red | ≥ 3 in
43 | Wire | W32 |  | UL1061 28 AWG Red | 28 AWG | Red | ≥ 3 in
44 | Wire | W33 |  | UL1061 28 AWG Red | 28 AWG | Red | ≥ 3 in
45 | Wire | W34 |  | UL1061 28 AWG Red | 28 AWG | Red | ≥ 3 in
46 | Wire | W35 |  | UL1061 28 AWG Black | 28 AWG | Black | ≥ 6 in

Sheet: Connections
Connections
Type |  | Harness
Part Number |  | SF-PDDC
Description
# | From | To | Conductor | Conductor PN | Twist With | Gauge | Length | From Contact PN | To Contact PN | Notes
1 | C1.1 | S2 | CBL11.Black | 2 Wire 18 AWG unshielded - Red/Black |  | 18 AWG | ≥ 6 in
2 | C1.2 | S1 | CBL11.Red | 2 Wire 18 AWG unshielded - Red/Black |  | 18 AWG | ≥ 6 in
3 | C2.1 | S22 | W35.Black | UL1061 28 AWG Black |  | 28 AWG | ≥ 6 in
4 | C2.2 | C14.4 | W10.Blue | UL1061 28 AWG Blue |  | 28 AWG | ≥ 9 in |  | 28-26 AWG Pin Crimp
5 | C3.1 | S2 | W12.Black | UL1061 28 AWG Black |  | 28 AWG | 6 in
6 | C3.2 | C4.4 | W11.Blue | UL1061 28 AWG Blue |  | 28 AWG | ≥ 9 in |  | 28-26 AWG Pin Crimp
7 | C4.1 | S2 | W13.Black | UL1061 28 AWG Black |  | 28 AWG | ≥ 3 in | 28-26 AWG Pin Crimp
8 | C4.2 | S1 | W24.Red | UL1061 28 AWG Red |  | 28 AWG | ≥ 3 in | 28-26 AWG Pin Crimp
9 | C4.3 | C5.4 | W1.Blue | UL1061 28 AWG Blue |  | 28 AWG | ≥ 30 in | 28-26 AWG Pin Crimp | 28-26 AWG Pin Crimp
10 | C5.1 | S4 | W14.Black | UL1061 28 AWG Black |  | 28 AWG | ≥ 3 in | 28-26 AWG Pin Crimp
11 | C5.2 | S3 | W25.Red | UL1061 28 AWG Red |  | 28 AWG | ≥ 3 in | 28-26 AWG Pin Crimp
12 | C5.3 | C6.4 | W3.Blue | UL1061 28 AWG Blue |  | 28 AWG | ≥ 30 in | 28-26 AWG Pin Crimp | 28-26 AWG Pin Crimp
13 | C6.1 | S6 | W15.Black | UL1061 28 AWG Black |  | 28 AWG | ≥ 3 in | 28-26 AWG Pin Crimp
14 | C6.2 | S5 | W26.Red | UL1061 28 AWG Red |  | 28 AWG | ≥ 3 in | 28-26 AWG Pin Crimp
15 | C6.3 | C7.4 | W4.Blue | UL1061 28 AWG Blue |  | 28 AWG | ≥ 30 in | 28-26 AWG Pin Crimp | 28-26 AWG Pin Crimp
16 | C7.1 | S8 | W16.Black | UL1061 28 AWG Black |  | 28 AWG | ≥ 3 in | 28-26 AWG Pin Crimp
17 | C7.2 | S7 | W27.Red | UL1061 28 AWG Red |  | 28 AWG | ≥ 3 in | 28-26 AWG Pin Crimp
18 | C7.3 | C8.4 | W5.Blue | UL1061 28 AWG Blue |  | 28 AWG | ≥ 30 in | 28-26 AWG Pin Crimp | 28-26 AWG Pin Crimp
19 | C8.1 | S10 | W17.Black | UL1061 28 AWG Black |  | 28 AWG | ≥ 3 in | 28-26 AWG Pin Crimp
20 | C8.2 | S9 | W28.Red | UL1061 28 AWG Red |  | 28 AWG | ≥ 3 in | 28-26 AWG Pin Crimp
21 | C8.3 | C9.4 | W6.Blue | UL1061 28 AWG Blue |  | 28 AWG | ≥ 30 in | 28-26 AWG Pin Crimp | 28-26 AWG Pin Crimp
22 | C9.1 | S12 | W18.Black | UL1061 28 AWG Black |  | 28 AWG | ≥ 3 in | 28-26 AWG Pin Crimp
23 | C9.2 | S11 | W29.Red | UL1061 28 AWG Red |  | 28 AWG | ≥ 3 in | 28-26 AWG Pin Crimp
24 | C10.1 | S14 | W19.Black | UL1061 28 AWG Black |  | 28 AWG | ≥ 3 in | 28-26 AWG Pin Crimp
25 | C10.2 | S13 | W30.Red | UL1061 28 AWG Red |  | 28 AWG | ≥ 3 in | 28-26 AWG Pin Crimp
26 | C11.1 | S16 | W20.Black | UL1061 28 AWG Black |  | 28 AWG | ≥ 3 in | 28-26 AWG Pin Crimp
27 | C11.2 | S15 | W34.Red | UL1061 28 AWG Red |  | 28 AWG | ≥ 3 in | 28-26 AWG Pin Crimp
28 | C11.3 | C10.4 | W9.Blue | UL1061 28 AWG Blue |  | 28 AWG | ≥ 30 in | 28-26 AWG Pin Crimp | 28-26 AWG Pin Crimp
29 | C12.1 | S18 | W21.Black | UL1061 28 AWG Black |  | 28 AWG | ≥ 3 in | 28-26 AWG Pin Crimp
30 | C12.2 | S17 | W31.Red | UL1061 28 AWG Red |  | 28 AWG | ≥ 3 in | 28-26 AWG Pin Crimp
31 | C12.3 | C11.4 | W8.Blue | UL1061 28 AWG Blue |  | 28 AWG | ≥ 30 in | 28-26 AWG Pin Crimp | 28-26 AWG Pin Crimp
32 | C13.1 | S20 | W22.Black | UL1061 28 AWG Black |  | 28 AWG | ≥ 3 in | 28-26 AWG Pin Crimp
33 | C13.2 | S19 | W32.Red | UL1061 28 AWG Red |  | 28 AWG | ≥ 3 in | 28-26 AWG Pin Crimp
34 | C13.3 | C12.4 | W2.Blue | UL1061 28 AWG Blue |  | 28 AWG | ≥ 30 in | 28-26 AWG Pin Crimp | 28-26 AWG Pin Crimp
35 | C14.1 | S22 | W23.Black | UL1061 28 AWG Black |  | 28 AWG | ≥ 3 in | 28-26 AWG Pin Crimp
36 | C14.2 | S21 | W33.Red | UL1061 28 AWG Red |  | 28 AWG | ≥ 3 in | 28-26 AWG Pin Crimp
37 | C14.3 | C13.4 | W7.Blue | UL1061 28 AWG Blue |  | 28 AWG | ≥ 30 in | 28-26 AWG Pin Crimp | 28-26 AWG Pin Crimp
38 | S1 | S3 | CBL1.Red | 2 Wire 18 AWG unshielded - Red/Black |  | 18 AWG | ≥ 2 ft
39 | S2 | S4 | CBL1.Black | 2 Wire 18 AWG unshielded - Red/Black |  | 18 AWG | ≥ 2 ft
40 | S3 | S5 | CBL2.Red | 2 Wire 18 AWG unshielded - Red/Black |  | 18 AWG | ≥ 2 ft
41 | S4 | S6 | CBL2.Black | 2 Wire 18 AWG unshielded - Red/Black |  | 18 AWG | ≥ 2 ft
42 | S5 | S7 | CBL3.Red | 2 Wire 18 AWG unshielded - Red/Black |  | 18 AWG | ≥ 2 ft
43 | S6 | S8 | CBL3.Black | 2 Wire 18 AWG unshielded - Red/Black |  | 18 AWG | ≥ 2 ft
44 | S7 | S9 | CBL4.Red | 2 Wire 18 AWG unshielded - Red/Black |  | 18 AWG | ≥ 2 ft
45 | S8 | S10 | CBL4.Black | 2 Wire 18 AWG unshielded - Red/Black |  | 18 AWG | ≥ 2 ft
46 | S9 | S11 | CBL5.Red | 2 Wire 18 AWG unshielded - Red/Black |  | 18 AWG | ≥ 2 ft
47 | S10 | S12 | CBL5.Black | 2 Wire 18 AWG unshielded - Red/Black |  | 18 AWG | ≥ 2 ft
48 | S11 | S13 | CBL6.Red | 2 Wire 18 AWG unshielded - Red/Black |  | 18 AWG | ≥ 2 ft
49 | S13 | S15 | CBL7.Red | 2 Wire 18 AWG unshielded - Red/Black |  | 18 AWG | ≥ 2 ft
50 | S14 | S12 | CBL6.Black | 2 Wire 18 AWG unshielded - Red/Black |  | 18 AWG | ≥ 2 ft
51 | S14 | S16 | CBL7.Black | 2 Wire 18 AWG unshielded - Red/Black |  | 18 AWG | ≥ 2 ft
52 | S15 | S17 | CBL8.Red | 2 Wire 18 AWG unshielded - Red/Black |  | 18 AWG | ≥ 2 ft
53 | S16 | S18 | CBL8.Black | 2 Wire 18 AWG unshielded - Red/Black |  | 18 AWG | ≥ 2 ft
54 | S17 | S19 | CBL9.Red | 2 Wire 18 AWG unshielded - Red/Black |  | 18 AWG | ≥ 2 ft
55 | S18 | S20 | CBL9.Black | 2 Wire 18 AWG unshielded - Red/Black |  | 18 AWG | ≥ 2 ft
56 | S19 | S21 | CBL10.Red | 2 Wire 18 AWG unshielded - Red/Black |  | 18 AWG | ≥ 2 ft
57 | S20 | S22 | CBL10.Black | 2 Wire 18 AWG unshielded - Red/Black |  | 18 AWG | ≥ 2 ft

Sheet: Labels
Labels
Type |  | Harness
Part Number |  | SF-PDDC
Description
# | Type | Manufacturer | Part Number | Description | Label Text

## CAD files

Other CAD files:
mechanical/resin mold/half mold negative-smooth.skp
mechanical/resin mold/half mold negative.skp
mechanical/resin mold/half mold-smooth-nowire-bottom-mold.skp
mechanical/resin mold/half mold-smooth-nowire-bottom.skp
mechanical/resin mold/half mold-smooth-nowire-resin-well-block-mold.skp
mechanical/resin mold/half mold-smooth-nowire-resin-well-block.skp
mechanical/resin mold/half mold-smooth-nowire-top-mold-topframe.skp
mechanical/resin mold/half mold-smooth-nowire-top-mold.skp
mechanical/resin mold/half mold-smooth-nowire-top.skp
mechanical/resin mold/half mold-smooth-nowire.skp
mechanical/resin mold/half mold-smooth.skp
mechanical/resin mold/half mold.skp
mechanical/resin mold/resin block-smooth-nowire.skp
mechanical/resin mold/resin block-smooth.skp
mechanical/resin mold/resin block.skp
structural/Structure-thin.skp
structural/Structure.skp

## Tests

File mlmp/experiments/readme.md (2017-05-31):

python.exe .\basic.py --path=C:\Users\volar\Downloads\magnatagatune\ --data_size=100 --rounds=5 --save=.\weights

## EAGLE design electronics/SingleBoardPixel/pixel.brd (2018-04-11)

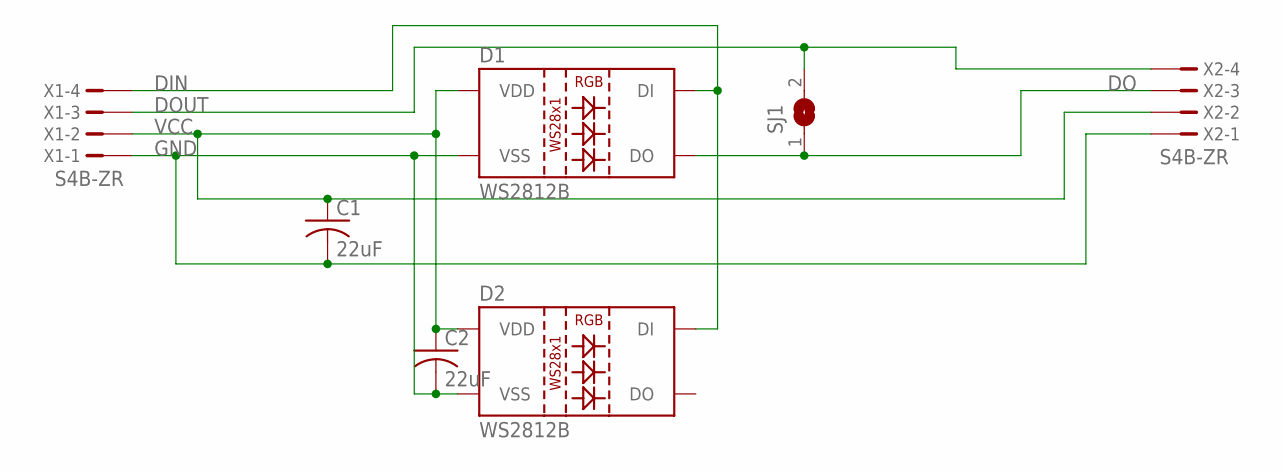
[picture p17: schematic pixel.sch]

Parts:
C1, C2: 22uF; C0402
D1, D2: WS2812B
SJ1: SJ
X1, X2: S4B-ZR

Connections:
DIN: D1.4 (DI), D2.4 (DI), X1.4
DO: D1.2 (DO), SJ1.1, X2.3
DOUT: SJ1.2, X1.3, X2.4
GND: C1.2, C2.2, D1.3 (VSS), D2.3 (VSS), X1.1, X2.1
VCC: C1.1, C2.1, D1.1 (VDD), D2.1 (VDD), X1.2, X2.2

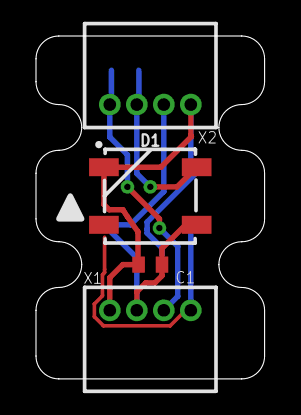
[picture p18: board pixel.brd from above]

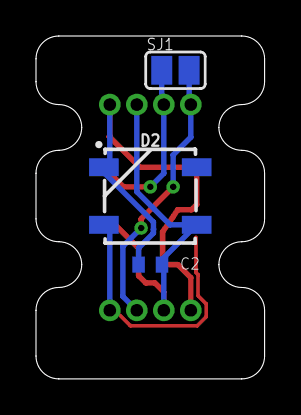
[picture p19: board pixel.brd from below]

Board: 2 copper layers, 12.7 x 19.1 mm, 7 parts (3 on the bottom side), 5 nets.

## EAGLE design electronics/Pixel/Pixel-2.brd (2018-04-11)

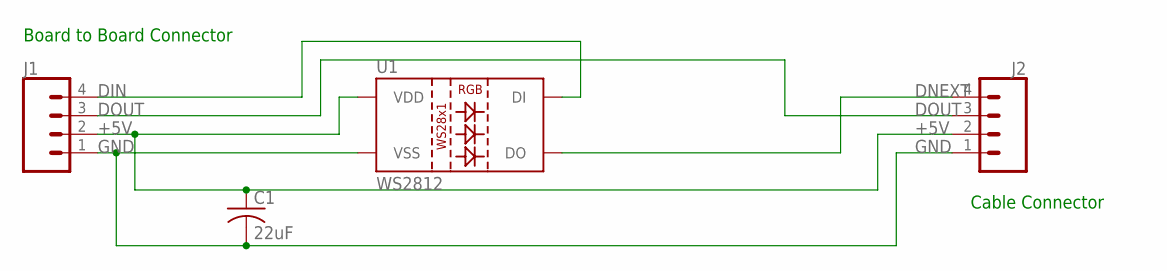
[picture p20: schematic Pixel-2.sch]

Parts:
C1: 22uF; C0402
J1, J2: CONN_04; 1X04
U1: WS2812; LED-TRICOLOR-5050-IC

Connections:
+5V: C1.1, J1.2, J2.2, U1.3 (VDD), U1.5 (VDD)
DIN: J1.4, U1.2 (DI)
DNEXT: J2.4, U1.1 (DO)
DOUT: J1.3, J2.3
GND: C1.2, J1.1, J2.1, U1.6 (VSS)

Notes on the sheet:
Cable Connector
Board to Board Connector

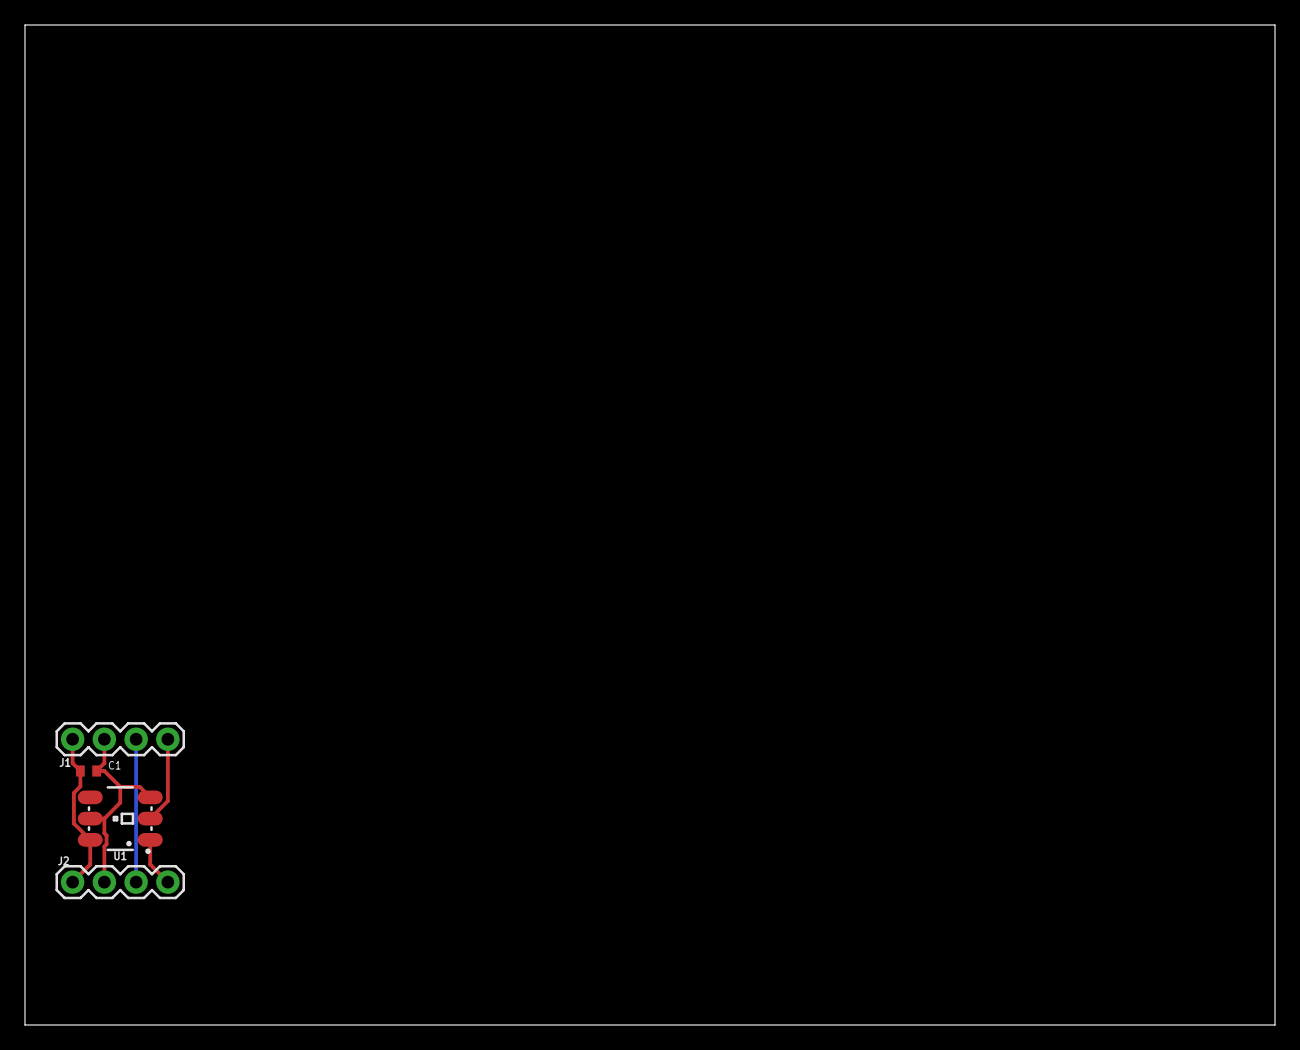
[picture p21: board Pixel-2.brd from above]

Board: 2 copper layers, 100.0 x 80.0 mm, 4 parts (0 on the bottom side), 5 nets.

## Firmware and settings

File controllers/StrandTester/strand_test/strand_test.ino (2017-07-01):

#include <Adafruit_NeoPixel.h>

#define PIN 0
#define LENGTH 21
#define ON 40
#define DELAY (1000 / LENGTH)

// Parameter 1 = number of pixels in strip
// Parameter 2 = Arduino pin number (most are valid)
// Parameter 3 = pixel type flags, add together as needed:
//   NEO_KHZ800  800 KHz bitstream (most NeoPixel products w/WS2812 LEDs)
//   NEO_KHZ400  400 KHz (classic 'v1' (not v2) FLORA pixels, WS2811 drivers)
//   NEO_GRB     Pixels are wired for GRB bitstream (most NeoPixel products)
//   NEO_RGB     Pixels are wired for RGB bitstream (v1 FLORA pixels, not v2)
//   NEO_RGBW    Pixels are wired for RGBW bitstream (NeoPixel RGBW products)
Adafruit_NeoPixel strip1 = Adafruit_NeoPixel(LENGTH + 1, PIN, NEO_GRB + NEO_KHZ800  );
Adafruit_NeoPixel strip2 = Adafruit_NeoPixel(LENGTH + 1, PIN+1, NEO_GRB + NEO_KHZ800  );
Adafruit_NeoPixel strip3 = Adafruit_NeoPixel(LENGTH + 1, PIN+2, NEO_GRB + NEO_KHZ800  );
Adafruit_NeoPixel strip4 = Adafruit_NeoPixel(LENGTH + 1, PIN+3, NEO_GRB + NEO_KHZ800  );

void setup() {
  // put your setup code here, to run once:

  strip1.begin();
  strip1.show(); // Initialize all pixels to 'off'

  strip2.begin();
  strip2.show(); // Initialize all pixels to 'off'

  strip3.begin();
  strip3.show(); // Initialize all pixels to 'off'

  strip4.begin();
  strip4.show(); // Initialize all pixels to 'off'
}

void loop() {
  // put your main code here, to run repeatedly:
  colorWipe(strip1.Color(ON, 0, 0), DELAY); // Red
  colorWipe(strip1.Color(0, ON, 0), DELAY); // Green
  colorWipe(strip1.Color(0, 0, ON), DELAY); // Blue
}

// Fill the dots one after the other with a color
void colorWipe(uint32_t c, uint8_t wait) {
  for(uint16_t i=0; i<strip1.numPixels(); i++) {
    if(i==strip1.numPixels()-1)
    {
      // hack for using a different neopixel as the tester
      uint8_t r = (0xFF0000 & c) >> 16;
      uint8_t g = (0xFF00 & c) >> 8;
      uint8_t b = 0xFF & c;
      c = strip1.Color(g,r,b);
    }
    
    strip1.setPixelColor(i, c);
    strip1.show();
    
    strip2.setPixelColor(i, c);
    strip2.show();
    
    strip3.setPixelColor(i, c);
    strip3.show();
    
    strip4.setPixelColor(i, c);
    strip4.show();
    delay(wait);
  }
}

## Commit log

2015-02-28 Initial commit of software and electronics
    Software: Various demo algorithms and the .NET library for controlling
    the starfield.
    Electronics: The pixel power and data distribution boards
    [PIxelDistributor3LED.sch]
2015-03-04 Cleanup, UI Improvements, and Driver Improvements
    Cleanup:
    Started effort to standardize naming conventions, add code folds, and
    wrap members with properties.
    UI Improvements:
    Added dropdown to select starfield type, IP address and port fields, and
    a property grid to allow driver configuration on the fly.
    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
2015-03-05 Added support for drivers in plugins
2015-03-09 Updating Simplex Driver Defaults
2015-03-15 Game of Life Driver
    This doesn't compute in the render window, so will need to have its
    processing broken out into a thread.
2015-03-15 Refactoring
    Moved the original test algorithm from the simulator to the starfield
    drivers project. Added a git attributes file to prevent git from merging
    assets.
2015-04-10 Fading Static Bug Fix
    For some colors, when a voxel faded to 0, it would flash brightly before
    staying at 0. This has been prevented and added as a driver option.
2015-04-10 ColorUtils.GetColorGradient Fix
    The bounding in the GetColorGradient doesn't work in all cases.
    Switching to simpler, more correct math.
2015-04-22 Project Refactoring
    Making it easier to build everything using fewer projects. Now each
    control program will build the drivers library and there is a single
    solution for all of the libs.
2015-04-22 DriverType Support
    Adding support for runtime identification of driver types.
2015-04-24 Tagging Driver Types
2015-04-26 Ambient Controller
    This controller will randomly walk through the algorithms tagged as
    ambient and transition smoothly between them. Great for not having to
    manually switch algorithms, not so great for showing off specific ones
    or customize them.
2016-02-27 Current Build
2016-03-26 Adding image blender
    This program blends up to 5 cameras into a single image. This composite
    image represents the heat map that will feed the presence and activity
    responsive display algorithms.
2016-03-26 Fixing camera 5 draw location
2016-04-04 Vision System Improvements and Tooling
    * Performance improvements for the vision system.
    * Presence simulator
    * Sample presence responsive algorithm
2016-04-06 fixing driver type
2016-04-06 adding presence trails driver
2016-05-21 stream replicator
    this takes the local OPC stream and forks it out the raspberry pis
2016-05-28 Presence Worker Thread
    Moving the timer to a worker thread to help with connectivity timeouts.
    If the server wasn't running, many instances of the client thread would
    be created starving the render thread of resources. This way, there is
    only ever one thread to do the polling.
2016-09-22 Ambient controller type filtering
2016-09-22 New drivers
2016-09-24 Driver List Generator
    Tool that generates lists of controllers with custom settings
2016-09-30 consolidating driver loading
2017-02-16 Models for Resin Work
    [half mold negative.skp, half mold.skp, resin block.skp]
2017-02-17 Smooth Molds for Resin Work
    [half mold negative-smooth.skp, half mold-smooth.skp, resin block-smooth.skp]
2017-02-24 More Documentation!
    Added controllers and started documenting the drivers
2017-02-25 Enabling Python Drivers
    Added an IronPython binding so that drivers can be written in python in
    addition to C#.
2017-03-14 v1 structural models
    [Structure-thin.skp, Structure.skp]
2017-03-25 new molds
    [half mold-smooth-nowire-bottom-mold.skp, half mold-smooth-nowire-bottom.skp, half mold-smooth-nowire-resin-well-block-mold.skp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]
2017-05-19 Arduino Strand Test Rig Code
2017-05-24 Adding starfield and utils projects to drivers
2017-06-10 New Driver
2017-06-10 Laser Cut Acrylic Case for Kinects
2017-06-16 Tweaks to build TheWorld solution
    Changed a bunch of relative paths to use SolutionDir, and changed a
    couple References to ProjectReferences
2018-04-11 electronics updates
    [BOM.csv, PIxelDistributor3LED.sch, PanelizationCalcs.xlsx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]

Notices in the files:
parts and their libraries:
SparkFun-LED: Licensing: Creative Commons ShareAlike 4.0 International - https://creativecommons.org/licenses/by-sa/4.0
